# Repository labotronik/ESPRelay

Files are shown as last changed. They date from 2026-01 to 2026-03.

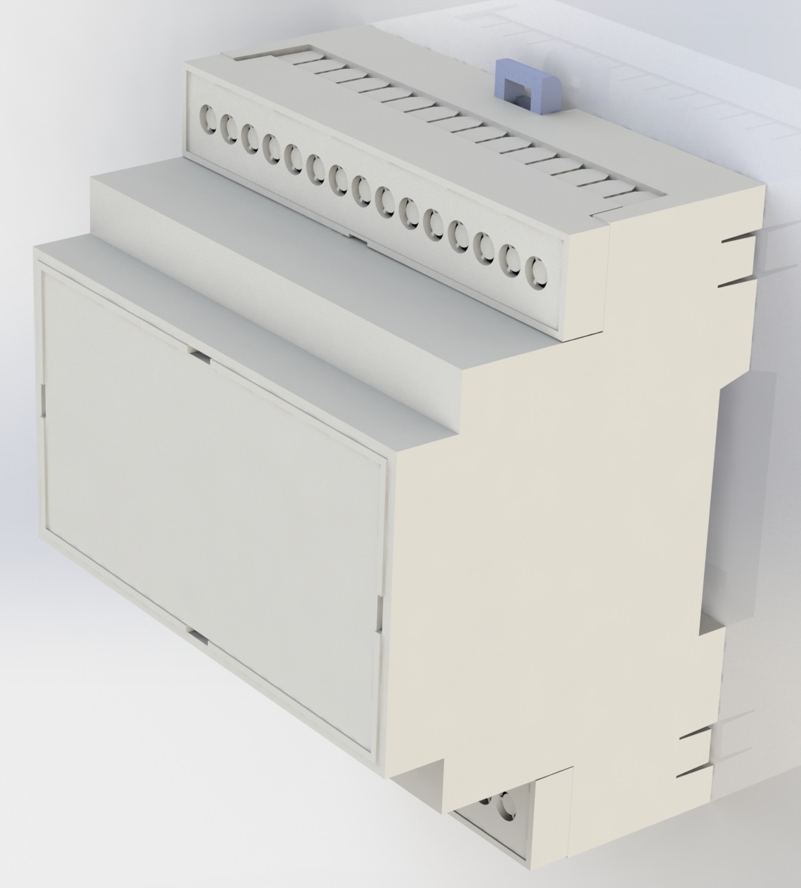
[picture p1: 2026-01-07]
kicad/enclosure/d5mg-1.snapshot.3/D5MG-FRONT.JPG

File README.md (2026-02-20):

# ESPRelay4

Documentation rapide d'utilisation de la carte relais (Ethernet, MQTT, Wi-Fi AP fallback, BLE) d'après le firmware actuel.

## 1) Démarrage et accès

- Le serveur HTTP écoute sur le port `80`.
- La page web principale est servie sur `/`.
- Réseau Ethernet W5500 actif au boot.

Configuration réseau par défaut (si aucun fichier de config):
- IP: `192.168.1.50`
- GW: `192.168.1.1`
- Mask: `255.255.255.0`
- DNS: `192.168.1.1`

## 2) API HTTP disponible

Endpoints principaux:
- `GET /api/state` -> état courant (inputs, relays, overrides, modules, réseau, volets, etc.)
- `GET /api/rules` -> règles simples + volets
- `GET /api/net` -> config réseau
- `GET /api/wifi` -> config/status Wi-Fi AP
- `GET /api/mqtt` -> config/status MQTT (transport actif, état GSM)
- `GET /api/backup` -> backup global
- `PUT /api/rules` -> applique des règles
- `PUT /api/net` -> applique réseau
- `PUT /api/wifi` -> active/désactive AP Wi-Fi
- `PUT /api/mqtt` -> applique config MQTT
- `POST /api/override` -> force un relais (`AUTO|FORCE_ON|FORCE_OFF`)
- `POST /api/shutter` -> commande volet (`UP|DOWN|STOP|AUTO`)
- `POST /api/ota` -> OTA firmware binaire
- `POST /api/otafs` -> OTA LittleFS binaire

Authentification:
- Défaut: `admin / admin`
- API de changement: `PUT /api/auth`

## 3) Utilisation MQTT (Ethernet + fallback GSM)

### 3.1 Principe de transport

Le firmware peut utiliser:
- broker local (Ethernet)
- broker GSM (A7670 + 1NCE)

Comportement actuel recommandé:
- tentative sur broker local d'abord
- si échec local, fallback sur broker GSM public (`gsm_mqtt_host`)

### 3.2 Paramètres MQTT (via `PUT /api/mqtt`)

Champs utiles:
- `enabled`: `1` pour activer MQTT
- `transport`: `ethernet`, `auto` ou `gsm`
- `host`, `port`, `user`, `pass`: broker principal (local)
- `gsm_mqtt_host`, `gsm_mqtt_port`, `gsm_mqtt_user`, `gsm_mqtt_pass`: broker GSM
- `client_id`: identifiant MQTT
- `base`: base topic (ex: `esprelay4`)
- `retain`: `1` recommandé pour récupérer un état immédiatement après subscribe
- `apn`, `gsm_user`, `gsm_pass`: paramètres data opérateur GSM

Exemple minimal:
```json
{
  "enabled": 1,
  "transport": "ethernet",
  "host": "192.168.1.43",
  "port": 1883,
  "gsm_mqtt_host": "82.64.24.196",
  "gsm_mqtt_port": 1883,
  "client_id": "ESPRelay4",
  "base": "esprelay4",
  "retain": 1,
  "apn": "iot.1nce.net",
  "gsm_user": "",
  "gsm_pass": ""
}
```

### 3.3 Commandes MQTT relais

Base topic par défaut: `esprelay4`

Relais 1:
- commande: `esprelay4/relay/1/set`
- payload: `ON`, `OFF`, `AUTO`, `TOGGLE`
- état: `esprelay4/relay/1/state`

Exemples:
```bash
mosquitto_sub -h 82.64.24.196 -p 1883 -t esprelay4/relay/1/state -v
mosquitto_pub -h 82.64.24.196 -p 1883 -t esprelay4/relay/1/set -m ON
```

Important:
- Si un relais est réservé à un volet, les overrides directs sont refusés/ignorés.
- `set ON/OFF` force le relais (override) tant que `AUTO` n'est pas envoyé.

### 3.4 Keepalive MQTT

- Paramètre firmware: `MQTT_KEEPALIVE_SECONDS`
- Valeur actuelle: `1800` secondes (30 min)

### 3.5 Mode GSM économie data

Quand transport actif = GSM:
- publication limitée aux états de pilotage utiles
- pas de discovery Home Assistant en boucle
- pas de télémétrie non essentielle en continu

## 4) Wi-Fi (AP fallback)

Le Wi-Fi est utilisé ici en mode AP local de maintenance.

- AP SoftAP activable/désactivable via `/api/wifi` ou MQTT:
  - `esprelay4/wifi/ap/set` avec payload `ON` ou `OFF`
- SSID par défaut: basé sur l'identifiant de la carte (`ESPRelay4-XXXXXX`)
- Mot de passe par défaut: `esprelay4`
- Captive portal simplifié (redirections vers l'IP AP)

## 5) BLE

Le firmware expose l'état en BLE (NimBLE):
- Device name: similaire au SSID (`ESPRelay4-XXXXXX`)
- Service UUID dynamique basé sur MAC:
  - `6E400001-B5A3-F393-E0A9-XXXXXXXXXXXX`
- Characteristic notify/read:
  - `6E400003-B5A3-F393-E0A9-XXXXXXXXXXXX` (READ + NOTIFY)
- Characteristic read:
  - `6E400004-B5A3-F393-E0A9-XXXXXXXXXXXX` (READ)

Particularités flux notify:
- cadence ~1 Hz
- tramage: `0x1E 0x1E + payload JSON + 0x1F`
- chunk BLE max ~160 bytes

Activation BLE:
- via MQTT: `esprelay4/ble/set` avec `ON`/`OFF`
- via API config BLE (`/ble.json`)

## 6) Règles / Volets / Priorités

Ordre de priorité des sorties:
1. Règles simples
2. Logique volet (si relais réservés)
3. Override manuel (MQTT/API) sur relais non réservés
4. Sécurité finale interlock volet

Conséquence:
- un `relay/x/set ON` écrase la règle tant que `AUTO` n'est pas renvoyé
- sur relais réservé volet: override interdit

## 7) Factory reset

- Maintenir le bouton factory (`IO0`) pendant ~10 secondes au boot
- Supprime les fichiers config: `/net.json`, `/mqtt.json`, `/rules.json`, `/auth.json`, `/wifi.json`, `/ble.json`
- Redémarrage automatique

## 8) Estimation conso data GSM

Hypothèses:
- Forfait: 500 Mo sur 10 ans
- Conso idle estimée: 10 Ko/jour
- 1 activation relais + lecture d'état MQTT: ~0,3 Ko

Seuil moyen:
- 500 Mo / 10 ans ~= 140 Ko/jour
- Après idle (10 Ko/jour), il reste ~130 Ko/jour pour les actions

Cas d'usage pouvant vider 500 Mo:
- ~430 activations/jour avec lecture d'état, sur la durée
- ou moins si réseau instable (reconnexions MQTT fréquentes)
- OTA via GSM: plusieurs Mo ponctuels

Exemple à risque:
- ~150 activations/jour + ~10 à 15 reconnexions MQTT/jour sur la durée

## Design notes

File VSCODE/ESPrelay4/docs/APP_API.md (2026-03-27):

# Documentation — ESPRelay4

## Vue d’ensemble
ESPRelay4 est un firmware ESP32‑S3 qui pilote des modules PCA9538 (I2C) et expose :
- une interface Web (LittleFS) ;
- une API HTTP JSON ;
- MQTT (avec auto‑découverte Home Assistant).

Fonctions principales :
- Entrées digitales (E*) via PCA9538 ;
- Relais (R*) via PCA9538 ;
- Règles logiques (FOLLOW/AND/OR/XOR/TOGGLE/PULSE) ;
- Volets (jusqu’à 2, 2 relais chacun, interlock + dead‑time) ;
- Réseau (DHCP ou statique) ;
- MQTT configurable ;
- Backup/restore complet ;
- Capteurs température DS18B20 (1‑Wire) et DHT22.

---

## Matériel & bus
### I2C / PCA9538
- PCA9538 adressés à partir de `0x70`.
- Scan automatique `0x70..0x73` (max 4 modules).
- Chaque module = 4 sorties + 4 entrées :
  - IO0..IO3 = relais (R)
  - IO4..IO7 = entrées (E)

### 1‑Wire / DS18B20
- Broche configurable : `PIN_ONEWIRE` (IO1 par défaut).

### DHT22
- Broche configurable : `PIN_DHT` (IO2 par défaut).

---

## Numérotation E/R
Les entrées et relais sont **globaux** :
- Module 1 : E1..E4, R1..R4
- Module 2 : E5..E8, R5..R8
- Module 3 : E9..E12, R9..R12
- Module 4 : E13..E16, R13..R16

L’UI propose une vue par module, mais les règles utilisent l’index global.

---

## Règles (rules.json)
Structure (résumé) :
```json
{
  "version": 2,
  "relays": [
    {
      "expr": { "op": "FOLLOW", "in": 1 },
      "invert": false,
      "onDelay": 0,
      "offDelay": 0,
      "pulseMs": 200
    }
  ],
  "shutters": []
}
```
### Opérateurs
- `FOLLOW` : suit une entrée
- `AND`, `OR`, `XOR` : logique multi‑entrées
- `TOGGLE_RISE` : bascule sur front montant
- `PULSE_RISE` : pulse sur front montant

### Volets (shutters[])
Jusqu’à 2 volets :
```json
{
  "name": "Volet 1",
  "up_in": 1,
  "down_in": 2,
  "up_relay": 1,
  "down_relay": 2,
  "mode": "hold",
  "priority": "stop",
  "deadtime_ms": 400,
  "max_run_ms": 25000
}
```
Contraintes :
- `up_relay` ≠ `down_relay`
- Les deux volets ne doivent pas partager de relais

---

## API HTTP
### GET /
Servir la page Web depuis LittleFS.

### GET /api/state
État global (entrées, relais, overrides, volets, capteurs, réseau).
```json
{
  "inputs": [0,1,...],
  "relays": [0,1,...],
  "override": [-1,0,1,...],
  "reserved": [0,1,...],
  "eth": { "link": 1, "ip": "192.168.1.50" },
  "shutter": { "enabled": 1, "name": "Volet 1", "up_relay": 1, "down_relay": 2, "move": "up", "cooldown_ms": 0 },
  "shutters": [
    { "enabled": 1, "name": "Volet 1", "up_relay": 1, "down_relay": 2, "move": "up", "cooldown_ms": 0 },
    { "enabled": 0 }
  ],
  "temps": [
    { "addr": "28FF...", "c": 21.45 },
    { "addr": "DHT22", "c": 22.10, "h": 48.2 }
  ],
  "modules": 2,
  "relays_per": 4,
  "inputs_per": 4,
  "total_relays": 8,
  "total_inputs": 8,
  "uptime_ms": 12345678
}
```

### GET /api/rules
Retourne le JSON complet des règles (relays + shutters).

### PUT /api/rules
Remplace toutes les règles.
- Validation taille `relays` = `total_relays`.
- Validation volets + conflits de relais.

### POST /api/override
```json
{ "relay": 1, "mode": "AUTO|FORCE_ON|FORCE_OFF" }
```
Refus si relais réservé par volet.

### POST /api/shutter
```json
{ "id": 1, "cmd": "UP|DOWN|STOP|AUTO" }
```
`id` ∈ {1,2}

### GET /api/net
Config réseau (inclut MAC Ethernet).

### PUT /api/net
```json
{
  "mode": "dhcp|static",
  "ip": "192.168.1.50",
  "gw": "192.168.1.1",
  "sn": "255.255.255.0",
  "dns": "192.168.1.1"
}
```

### GET /api/mqtt
Config MQTT (inclut état connecté).

### PUT /api/mqtt
```json
{
  "enabled": 1,
  "transport": "ethernet|gsm|auto",
  "host": "192.168.1.43",
  "port": 1883,
  "user": "",
  "pass": "",
  "client_id": "ESPRelay4",
  "base": "esprelay4",
  "discovery_prefix": "homeassistant",
  "retain": 1,
  "apn": "iot.1nce.net",
  "gsm_user": "",
  "gsm_pass": ""
}
```

Règle transport:
- `gsm` : active uniquement le client MQTT GSM.
- `ethernet` : active uniquement le client MQTT Ethernet.
- `auto` : active le client MQTT Ethernet, et active aussi le client MQTT GSM si `gsm_mqtt_host` est configuré.

### GET /api/backup
Retourne un backup complet :
```json
{ "rules": { ... }, "net": { ... }, "mqtt": { ... } }
```

### PUT /api/backup
Applique et redémarre la carte.

---

## MQTT (Home Assistant)
### Disponibilité
`<base>/status` = `online|offline`

### Relais
- `base/relay/<n>/set` (ON/OFF/AUTO)
- `base/relay/<n>/state`

### Entrées
- `base/input/<n>/state`

### Volets
2 covers :
- `base/shutter/1/set` / `base/shutter/1/state`
- `base/shutter/2/set` / `base/shutter/2/state`
Payloads : OPEN / CLOSE / STOP

### Températures
DS18B20 :
- `base/temp/<n>/state`

DHT22 :
- Température : `base/temp/dht/state`
- Humidité : `base/hum/dht/state`

---

## UI Web
Onglets :
- Dashboard : état entrées/relais/volets + capteurs si détectés
- Programmation : règles + volets 1/2
- JSON : vue JSON complet
- Réseau : IP + MQTT
- Backup : export / import

---

## Notes
- `millis()` overflow ~49,7 jours → uptime repart à 0.
- Les relais réservés par volet ignorent overrides et règles simples.

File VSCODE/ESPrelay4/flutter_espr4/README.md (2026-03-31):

# flutter_espr4

A new Flutter project.

## Getting Started

This project is a starting point for a Flutter application.

A few resources to get you started if this is your first Flutter project:

- [Learn Flutter](https://docs.flutter.dev/get-started/learn-flutter)
- [Write your first Flutter app](https://docs.flutter.dev/get-started/codelab)
- [Flutter learning resources](https://docs.flutter.dev/reference/learning-resources)

For help getting started with Flutter development, view the
[online documentation](https://docs.flutter.dev/), which offers tutorials,
samples, guidance on mobile development, and a full API reference.

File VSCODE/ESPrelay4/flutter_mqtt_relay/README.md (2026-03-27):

# flutter_mqtt_relay

Application Flutter MQTT pour piloter la carte ESPRelay4.

## Lancement

```bash
cd flutter_mqtt_relay
flutter pub get
flutter run
```

## Configuration MQTT

Dans l'onglet `MQTT`:

- `Broker host`: IP ou DNS du broker.
- `Broker port`: port MQTT (1883 par defaut).
- `Username` / `Password`: optionnel.
- `Base topic`: ex. `esprelay4`.
- `Client ID`: identifiant MQTT du client Flutter.

Puis cliquer `Save + Connect`.

## Setup relais

Dans l'onglet `Setup`, vous pouvez renommer les relais `R1..R4`.
Les noms sont sauvegardes localement dans l'application.

## Topics utilises

Commandes relais:

- `<base>/relay/1/set` payload `ON|OFF|AUTO`

Etats ecoutes:

- `<base>/status` (`online/offline`)
- `<base>/net/ip`
- `<base>/relay/<n>/state`
- `<base>/input/<n>/state`
- `<base>/vin/<n>/state`

L'interface reprend la presentation de la page Ethernet:

- bandeau de statuts (pills),
- onglet `Input` dedie aux etats des entrees `E1..E4` et `VIN`,
- cartes modules (dashboard),
- lignes relais avec etat/entree et actions `ON/OFF/AUTO`.

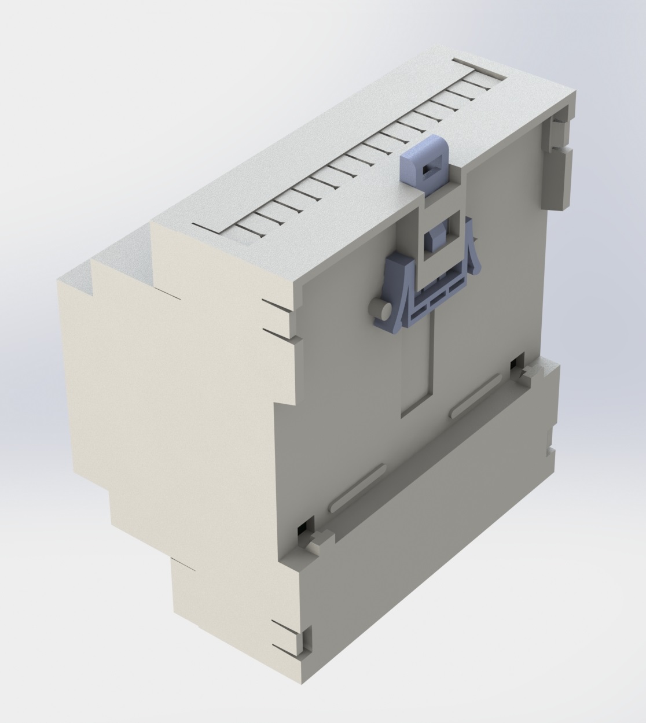
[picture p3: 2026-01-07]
kicad/enclosure/d5mg-1.snapshot.3/D5MG-REAR.JPG

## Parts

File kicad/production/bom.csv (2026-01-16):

Designator | Footprint | Quantity | Value | LCSC Part #
C1, C10, C11, C13, C2, C4, C5, C6, C8, C9 | 0402 | 10 | 100nF
C12 | 0805 | 1 | 10µF
C14 | 0402 | 1 | 22nF
C15, C17 | 0402 | 2 | 6.8nF
C16, C20, C7 | 0402 | 3 | 10nF
C18, C19 | 0402 | 2 | 12pF
C21 | 0402 | 1 | 4.7µF
C3 | CP_Elec_4x5.4 | 1 | 10µF
D1 | D_SMB | 1 | SMBJ12A
D2, D3, D4 | D_SMA | 3 | B230A-13-F
D5 | 0603 | 1 | LED LTST-C193TGKT-5A
F1 | 0154250DR littelfuse 10.62 3.81 | 1 | Fuse 3A
J1 | PhoenixContact_MCV_1,5_2-G-3.5_1x02_P3.50mm_Vertical | 1 | POWER_INPUT
J10, J7, J8, J9 | PhoenixContact_MCV_1,5_3-G-3.5_1x03_P3.50mm_Vertical | 4 | Screw_Terminal_01x03
J11 | PhoenixContact_MCV_1,5_6-G-3.5_1x06_P3.50mm_Vertical | 1 | Screw_Terminal_01x06
J2 | USB_C_Receptacle_G-Switch_GT-USB-7051x | 1 | GT-USB-7051A
J3 | Molex_54548-1071_1x10-1MP_P0.5mm_Horizontal | 1 | MOLEX 545480671
J4 | RJ12_Amphenol_54601-x06_Horizontal | 1 | RJ12
J5 | a7670c module | 1 | A7670C MODULE
J6 | RJ45_Hanrun_HR911105A_Horizontal | 1 | HR911105A
JP1 | PinHeader_1x02_P2.54mm_Vertical | 1 | Jumper_2_Bridged
K1, K2, K3, K4 | Relay_SPDT_Schrack-RT1-16A-FormC_RM5mm | 4 | RZ03-1C4-D012
Q1 | SOIC127P1030X245-18N | 1 | TBD62083AFG_EL
R1, R2, R6 | 0402 | 3 | 10k
R10, R11, R13, R9 | 0402 | 4 | 49.9
R12 | 0402 | 1 | 10
R14, R7, R8 | 0402 | 3 | 1k
R15 | 0402 | 1 | 1M
R16 | 0402 | 1 | 12.4k 1%
R17, R18, R19, R20 | 0805 | 4 | 2.2k
R21, R22, R23, R24, R3, R5 | 0402 | 6 | 4k7
R4 | 0402 | 1 | 680
SW1 | SW_Tactile_SPST_NO_Straight_CK_PTS636Sx25SMTRLFS | 1 | SW_Push
U1 | TO-263-3_TabPin2 | 1 | MC7805BD2TR4G
U2 | ESP32-S3-WROOM-1 | 1 | ESP32-S3-WROOM-1-N4
U3 | TO-252-2 | 1 | LF33CDT-TR
U4 | NXP_VQFN-16-1EP_4x4mm_P0.65mm_EP2.1x2.1mm | 1 | PCA9538BS
U5 | LQFP-48_7x7mm_P0.5mm | 1 | W5500
U6 | SOP-16_4.4x10.4mm_P1.27mm | 1 | TCMT4100
Y1 | Crystal_SMD_2016-4Pin_2.0x1.6mm | 1 | X201625MOB4SI - 25Mhz

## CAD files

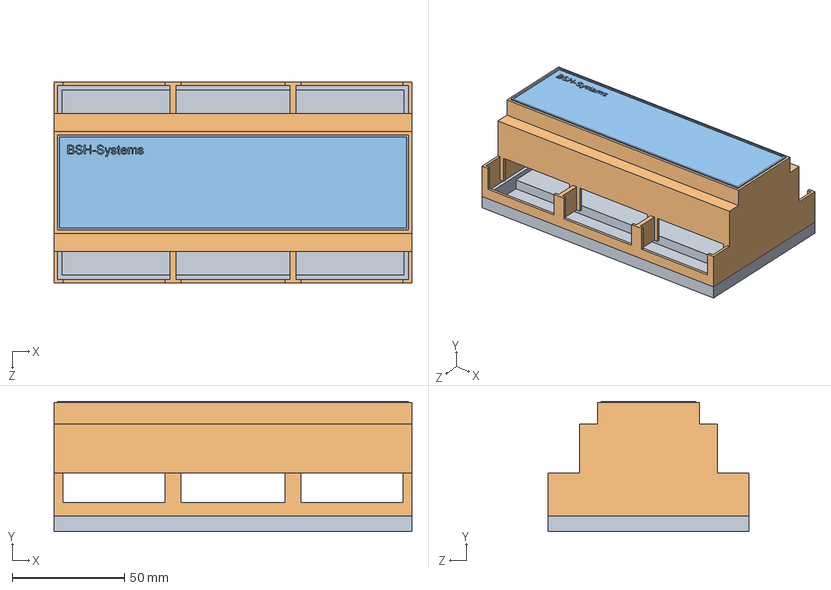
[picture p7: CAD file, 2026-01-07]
kicad/step files/User Library-D9MG_Asm.STEP
159.5 x 58.0 x 89.5 mm
D9MG_Bottom_Å« π¼«½τá¡¿ε
D9MG_Top_Å« π¼«½τá¡¿ε
D9MG_Closer_BSH_Å« π¼«½τá¡¿ε

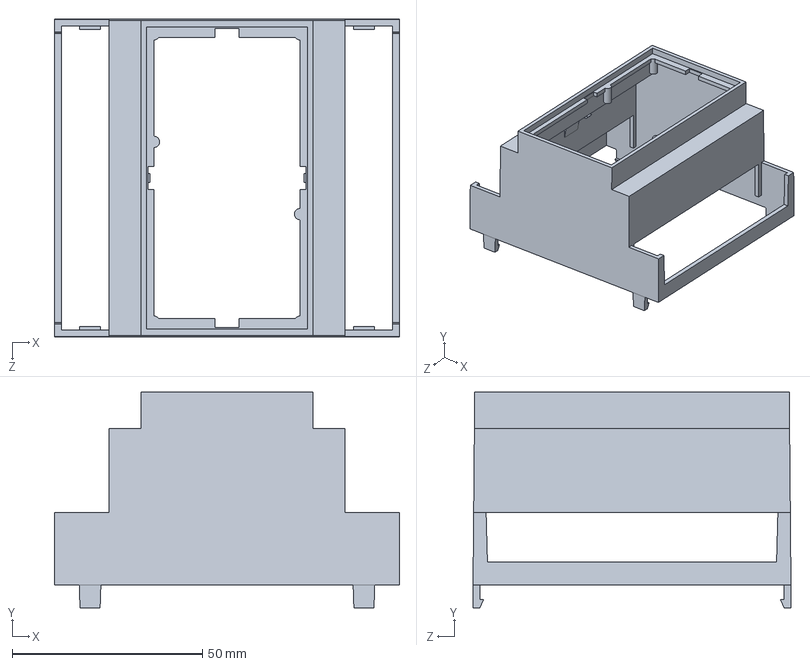
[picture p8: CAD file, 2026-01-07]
kicad/enclosure/d5mg-1.snapshot.3/D5MG-BODY.SLDPRT
90.7 x 56.7 x 83.6 mm

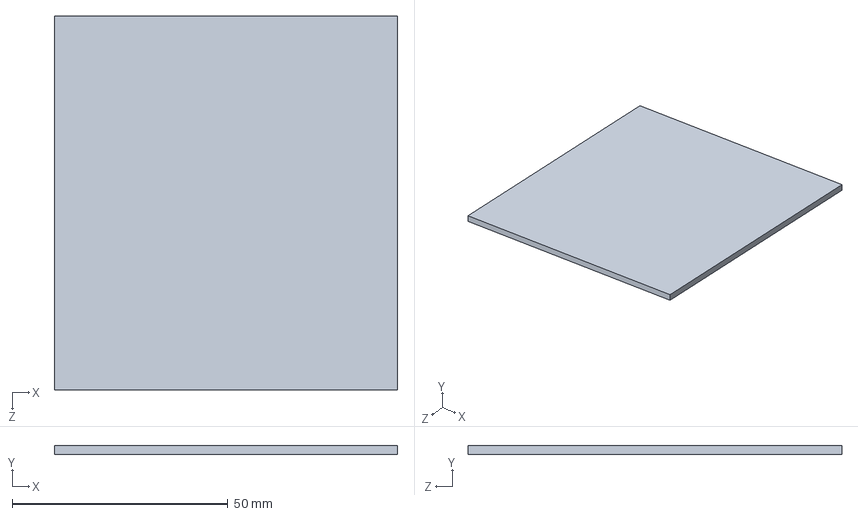
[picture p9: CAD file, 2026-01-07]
kicad/enclosure/d5mg-1.snapshot.3/PCB-BOT.SLDPRT
79.5 x 2.00 x 86.6 mm

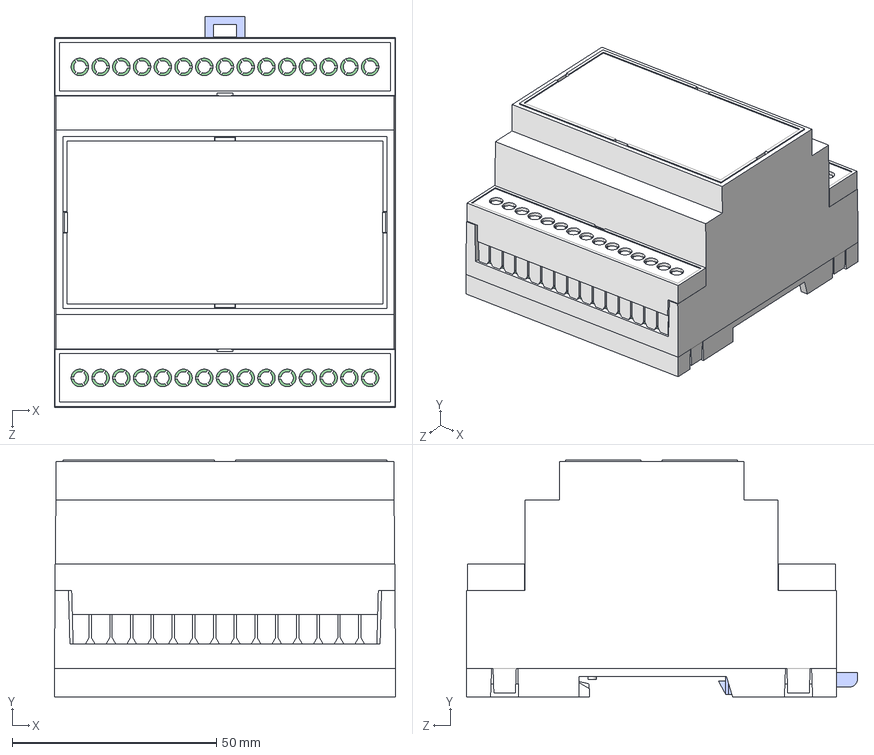
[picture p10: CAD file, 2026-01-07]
kicad/enclosure/d5mg-1.snapshot.3/D5MG.STEP
83.6 x 58.0 x 95.8 mm
D5MG-BODY
PCB-TOP
PCB-MID
PCB-BOT
D5MG-BASE
D5MG-COVER
D5MG-GUARD x 2
D5MG-WALL CLIP

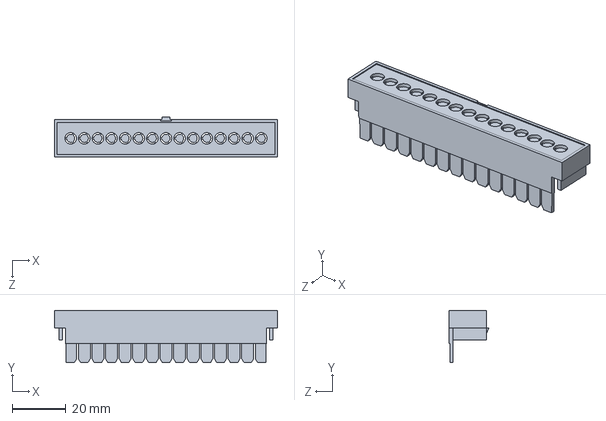
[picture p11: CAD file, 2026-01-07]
kicad/enclosure/d5mg-1.snapshot.3/D5MG-GUARD.SLDPRT
83.2 x 19.5 x 14.9 mm

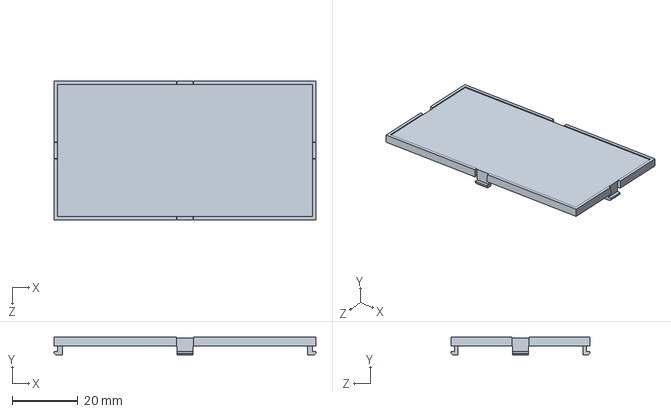
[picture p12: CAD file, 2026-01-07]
kicad/enclosure/d5mg-1.snapshot.3/D5MG-COVER.SLDPRT
79.5 x 5.40 x 42.2 mm

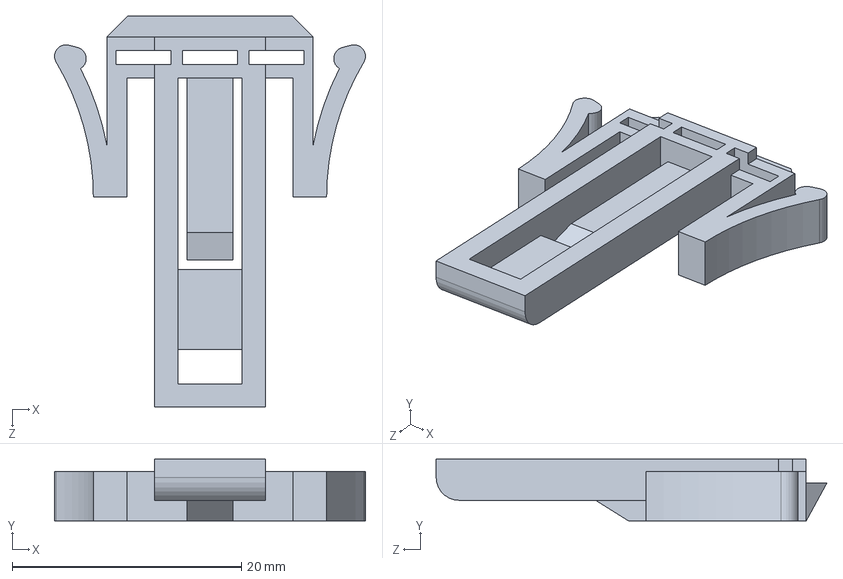
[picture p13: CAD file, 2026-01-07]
kicad/enclosure/d5mg-1.snapshot.3/D5MG-WALL CLIP.SLDPRT
27.1 x 5.40 x 34.1 mm

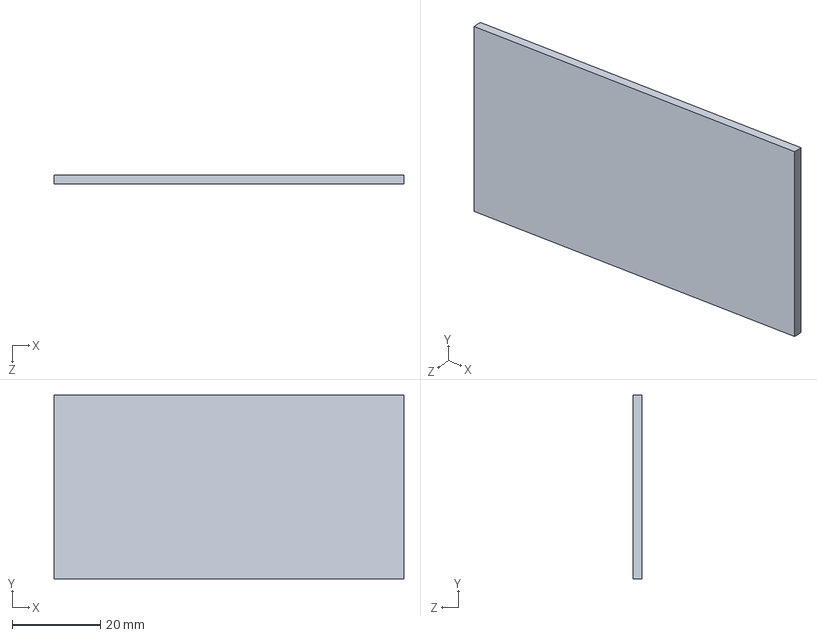
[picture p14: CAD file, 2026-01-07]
kicad/enclosure/d5mg-1.snapshot.3/PCB-TOP.SLDPRT
79.5 x 41.7 x 2.00 mm

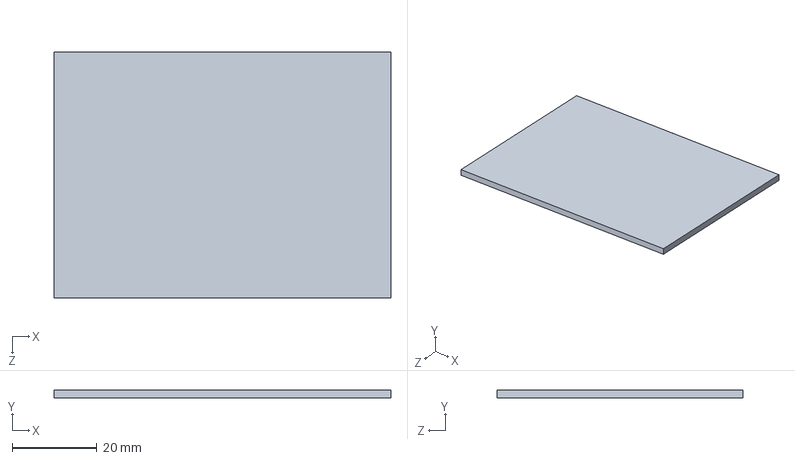
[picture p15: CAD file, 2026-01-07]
kicad/enclosure/d5mg-1.snapshot.3/PCB-MID.SLDPRT
79.5 x 2.00 x 58.1 mm

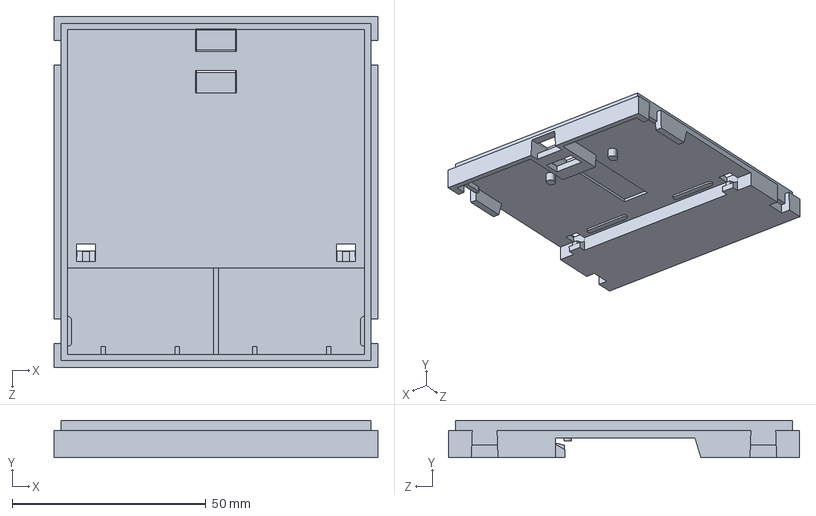
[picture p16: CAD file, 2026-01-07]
kicad/enclosure/d5mg-1.snapshot.3/D5MG-BASE.SLDPRT
83.6 x 9.60 x 90.7 mm

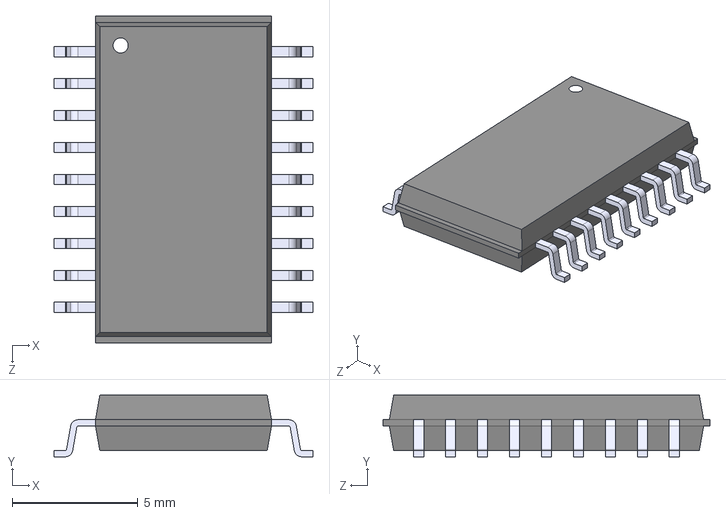
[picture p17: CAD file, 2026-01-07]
kicad/TBD62083AFG_EL/TBD62083AFG_EL.step
10.3 x 2.45 x 13.0 mm

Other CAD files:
kicad/enclosure/d5mg-1.snapshot.3/D5MG.SLDASM

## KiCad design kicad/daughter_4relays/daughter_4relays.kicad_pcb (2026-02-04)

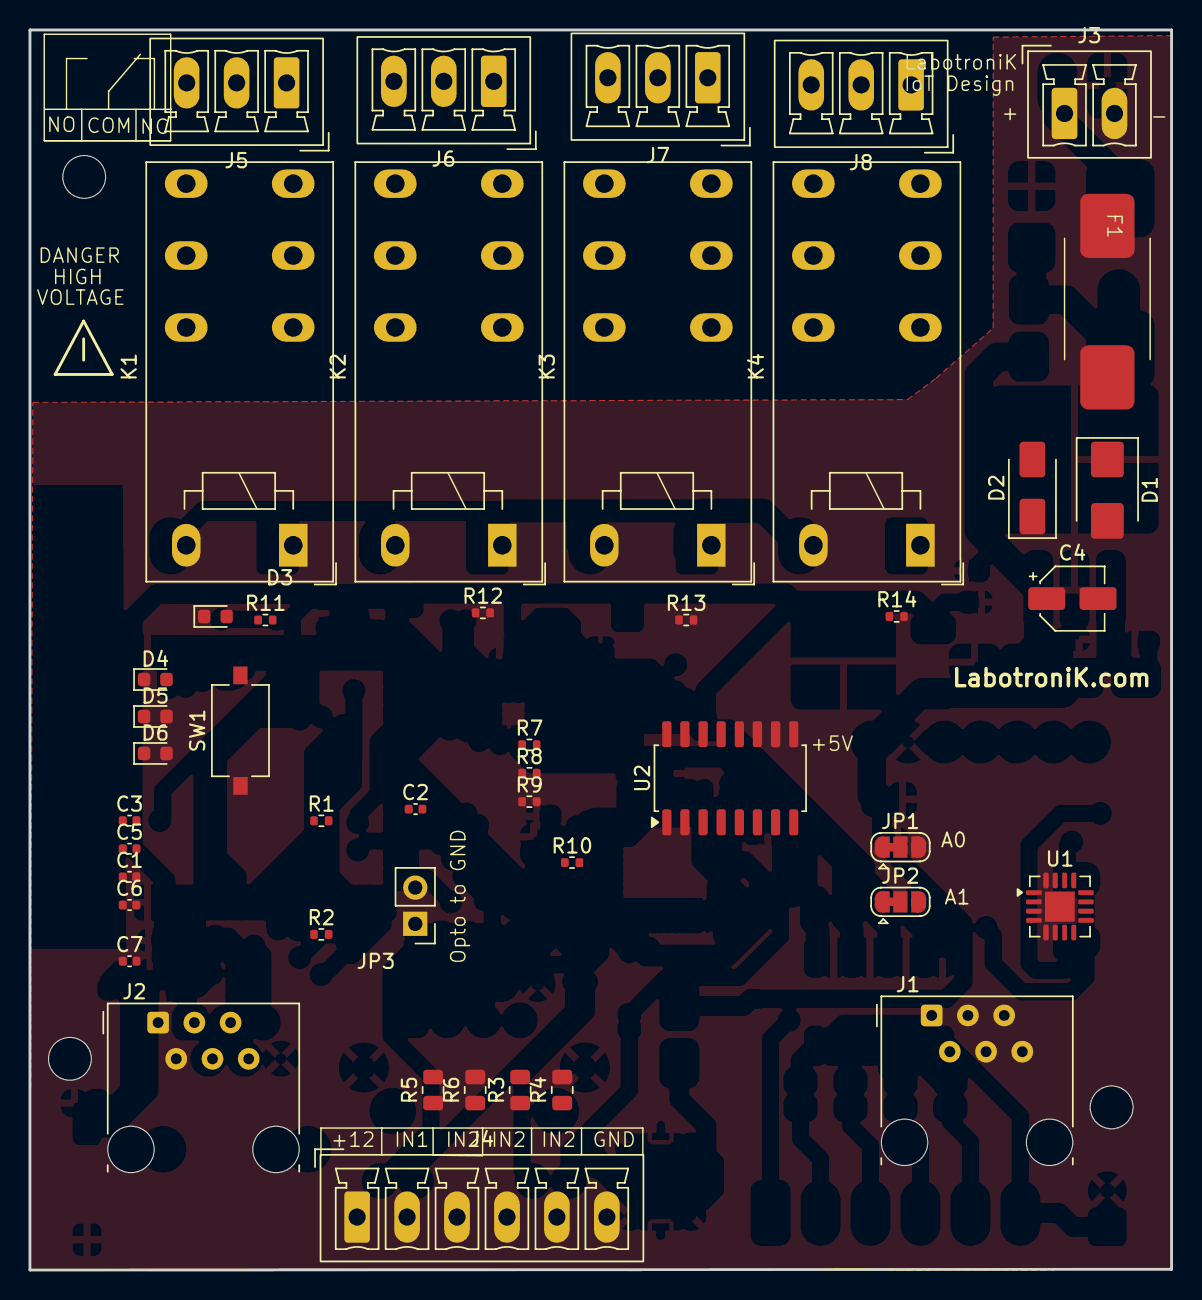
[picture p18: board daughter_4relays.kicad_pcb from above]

Board: 2 copper layers, 80.0 x 86.9 mm, 46 parts (0 on the bottom side), 47 nets, no tracks yet.

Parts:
C1, C2, C3, C5, C6, C7: 100nF; C_0402_1005Metric
C4: 10µF; CP_Elec_4x5.4
D1: SMBJ12A; D_SMB
D2: B230A-13-F; D_SMA
D3, D4, D5, D6: LED LTST-C193TGKT-5A; LED_0603_1608Metric
F1: Fuse 3A; 0154250DR littelfuse 10.62 3.81
J1, J2: RJ12; RJ12_Amphenol_54601-x06_Horizontal
J3: POWER_INPUT; PhoenixContact_MCV_1,5_2-G-3.5_1x02_P3.50mm_Vertical
J4: Screw_Terminal_01x06; PhoenixContact_MCV_1,5_6-G-3.5_1x06_P3.50mm_Vertical
J5, J6, J7, J8: Screw_Terminal_01x03; PhoenixContact_MCV_1,5_3-G-3.5_1x03_P3.50mm_Vertical
JP1, JP2: SolderJumper_3_Bridged12; SolderJumper-3_P1.3mm_Bridged12_RoundedPad1.0x1.5mm
JP3: Jumper_2_Bridged; PinHeader_1x02_P2.54mm_Vertical
K1, K2, K3, K4: RZ03-1C4-D012; Relay_SPDT_Schrack-RT1-16A-FormC_RM5mm
R1, R2: 10k; R_0402_1005Metric
R3, R4, R5, R6: 2.2k; R_0805_2012Metric
R7, R8, R9, R10: 4k7; R_0402_1005Metric
R11, R12, R13, R14: 680; R_0402_1005Metric
SW1: SW_Push; SW_Tactile_SPST_NO_Straight_CK_PTS636Sx25SMTRLFS
U1: PCA9538BS; NXP_VQFN-16-1EP_4x4mm_P0.65mm_EP2.1x2.1mm
U2: TCMT4100; SOP-16_4.4x10.4mm_P1.27mm

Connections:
+3.3V: C1.1, C2.1, C6.1, J1.1, J2.1, JP1.3 (B), JP2.3 (B), R1.1, R2.2, R7.1, R8.1, R9.1, R10.1, U1.14 (V_{DD})
+12V: C4.1, C5.1, C7.1, D2.1 (K), J4.1
/IO1: J1.4, J2.4
/IO2: J1.5, J2.5
/SCL: J1.3, J2.3, U1.12 (SCL)
/SDA: J1.2, J2.2, U1.13 (SDA)
/input/IN1: J4.2, R5.1
/input/IN2: J4.3, R6.1
/input/IN3: J4.4, R3.1
/input/IN4: J4.5, R4.1
/input/OPTO_GND: J4.6, JP3.1 (A), U2.2, U2.4, U2.6, U2.8
/input/input1: R8.2, U1.7 (IO4), U2.16
/input/input2: R9.2, U1.8 (IO5), U2.14
/input/input3: R7.2, U1.9 (IO6), U2.12
/input/input4: R10.2, U1.10 (IO7), U2.10
/relais/PWR_KM1: K1.A1, R11.1
/relais/PWR_KM2: K2.A1, R12.1
/relais/PWR_KM3: K3.A1, R13.1
/relais/PWR_KM4: K4.A1, R14.1
GND: C1.2, C2.2, C3.2, C6.2, C7.2, D3.1 (K), D4.1 (K), D5.1 (K), D6.1 (K), J1.6, J2.6, JP1.1 (A), JP2.1 (A), JP3.2 (B), K1.A2, K2.A2, K3.A2, K4.A2, SW1.1, U1.6 (V_{SS}), U1.17 (V_{SS}), U2.9, U2.11, U2.13, U2.15
unnamed: C3.1, R1.2, SW1.2
unnamed: D1.1 (A1), D2.2 (A), F1.2
unnamed: C4.2, C5.2, D1.2 (A2), J3.1
unnamed: D3.2 (A), R11.2
unnamed: D4.2 (A), R12.2
unnamed: D5.2 (A), R13.2
unnamed: D6.2 (A), R14.2
unnamed: F1.1, J3.2
unnamed: J5.1, K1.12
unnamed: J5.2, K1.11
unnamed: J5.3, K1.14
unnamed: J6.1, K2.12
unnamed: J6.2, K2.11
unnamed: J6.3, K2.14
unnamed: J7.1, K3.12
unnamed: J7.2, K3.11
unnamed: J7.3, K3.14
unnamed: J8.1, K4.12
unnamed: J8.2, K4.11
unnamed: J8.3, K4.14
unnamed: JP1.2 (C), U1.15 (A0)
unnamed: JP2.2 (C), U1.16 (A1)
unnamed: R3.2, U2.5
unnamed: R4.2, U2.7
unnamed: R5.2, U2.1
unnamed: R6.2, U2.3
unnamed: R2.1, U1.1 (~RESET)

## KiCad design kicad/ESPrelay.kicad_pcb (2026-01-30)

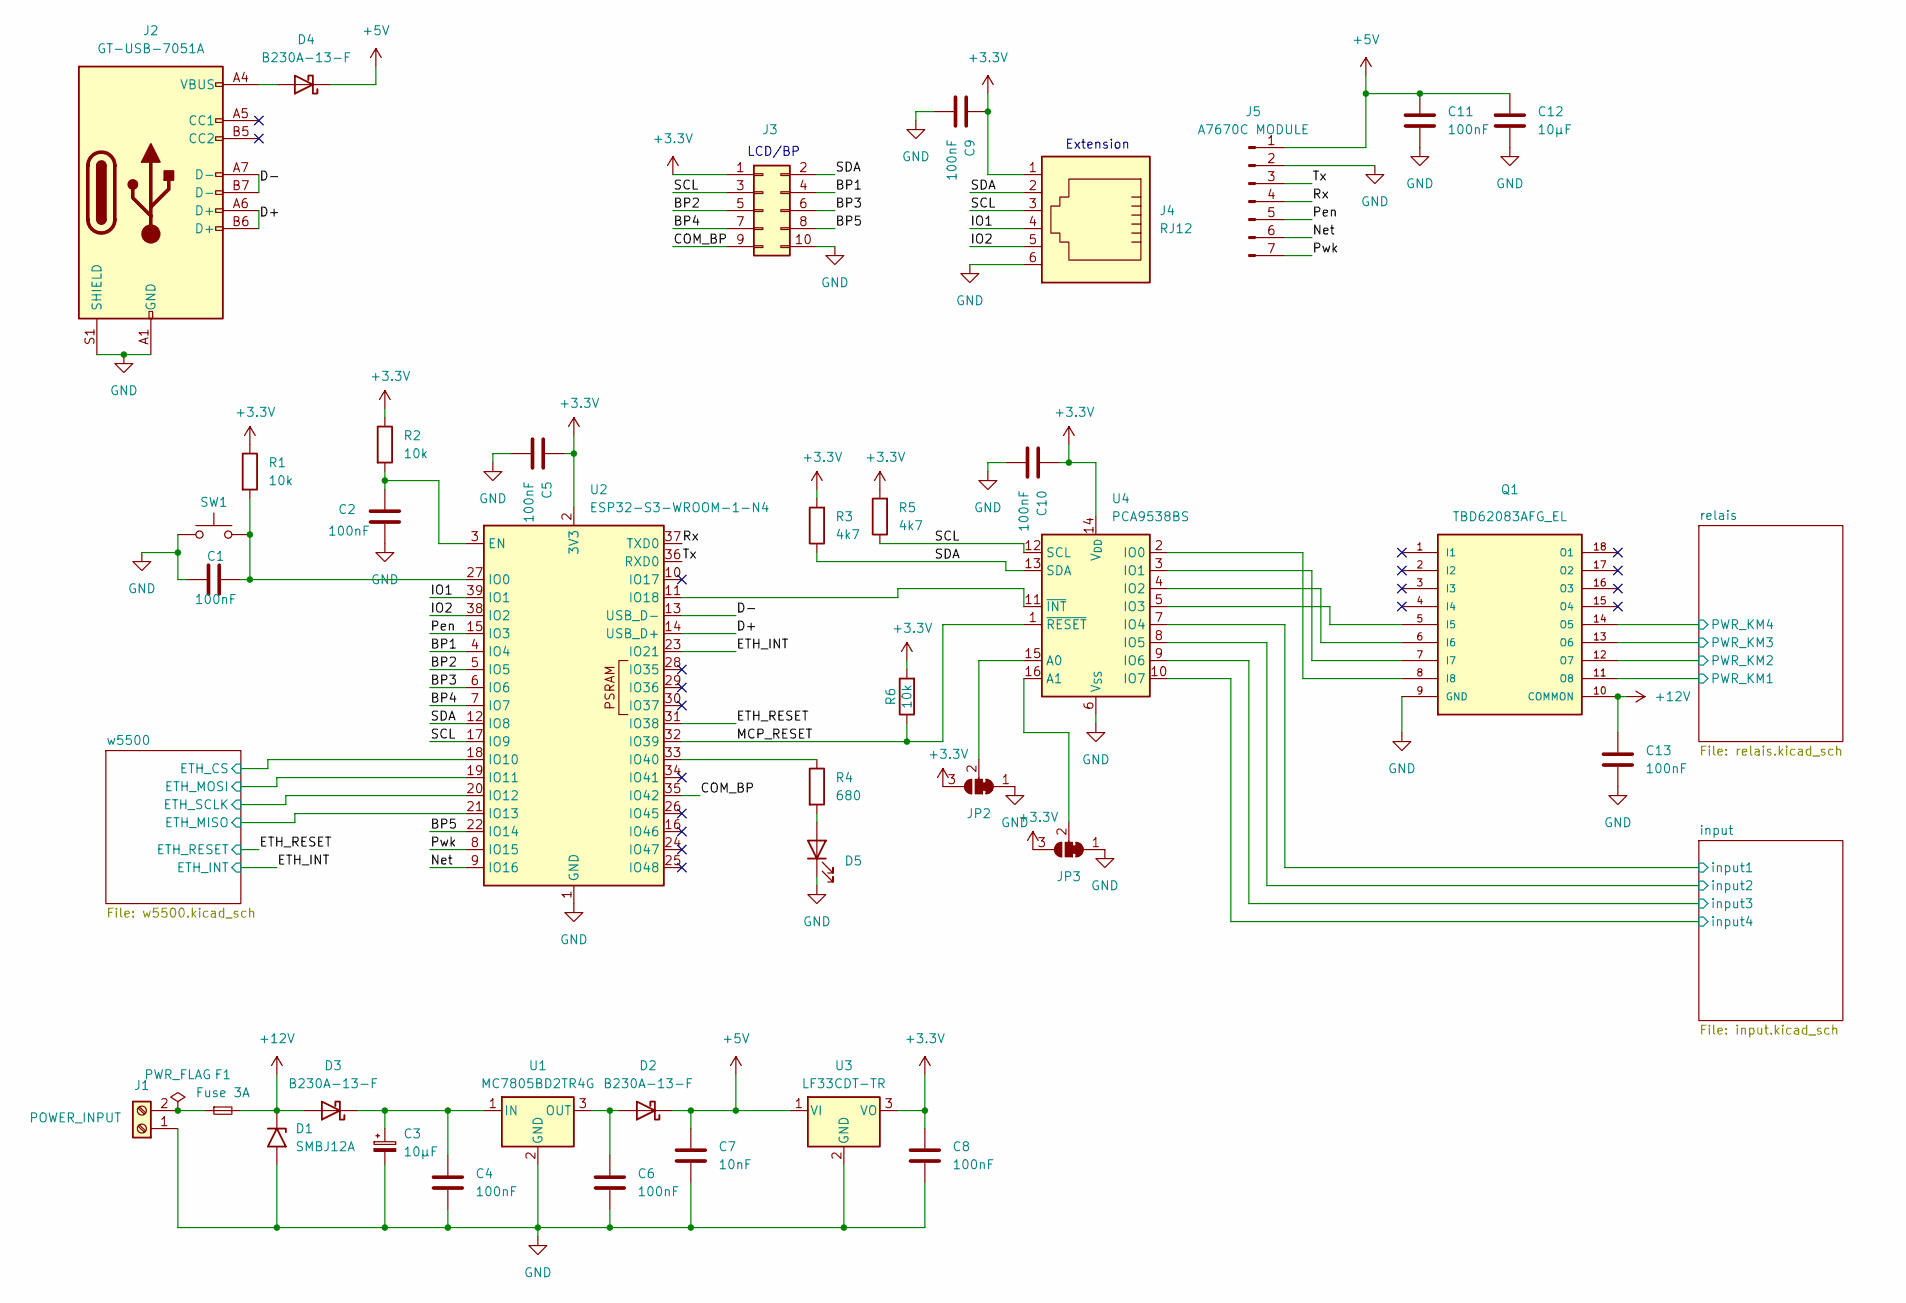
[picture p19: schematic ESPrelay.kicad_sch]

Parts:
C1, C2, C4, C5, C6, C8, C9, C10, C11, C13: 100nF; C_0402_1005Metric
C3: 10µF; CP_Elec_4x5.4
C7: 10nF; R_0402_1005Metric
C12: 10µF; C_0805_2012Metric
D1: SMBJ12A; D_SMB
D2, D3, D4: B230A-13-F; D_SMA
D5: LED LTST-C193TGKT-5A; LED_0603_1608Metric
F1: Fuse 3A; 0154250DR littelfuse 10.62 3.81
J1: POWER_INPUT; PhoenixContact_MCV_1,5_2-G-3.5_1x02_P3.50mm_Vertical
J2: GT-USB-7051A; USB_C_Receptacle_G-Switch_GT-USB-7051x
J3: MOLEX 545480671; Molex_54548-1071_1x10-1MP_P0.5mm_Horizontal
J4: RJ12; RJ12_Amphenol_54601-x06_Horizontal
J5: A7670C MODULE; a7670c module
JP2, JP3: SolderJumper_3_Bridged12; SolderJumper-3_P1.3mm_Bridged12_RoundedPad1.0x1.5mm
Q1: TBD62083AFG_EL; SOIC127P1030X245-18N; MOUSER_PART_NUMBER 757-TBD62083AFGEL
R1, R2, R6: 10k; R_0402_1005Metric
R3, R5: 4k7; R_0402_1005Metric
R4: 680; R_0402_1005Metric
SW1: SW_Push; SW_Tactile_SPST_NO_Straight_CK_PTS636Sx25SMTRLFS
U1: MC7805BD2TR4G; TO-263-3_TabPin2
U2: ESP32-S3-WROOM-1-N4; ESP32-S3-WROOM-1
U3: LF33CDT-TR; TO-252-2
U4: PCA9538BS; NXP_VQFN-16-1EP_4x4mm_P0.65mm_EP2.1x2.1mm

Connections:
+3.3V: C5.1, C8.1, C9.1, C10.1, J3.1, J4.1, JP2.3 (B), JP3.3 (B), R1.1, R2.1, R3.2, R5.2, R6.2, U2.2 (3V3), U3.3 (VO), U4.14 (V_{DD}); also elsewhere on the board
+5V: C7.1, C11.1, C12.1, D2.1 (K), D4.1 (K), J5.1, U3.1 (VI)
+12V: C13.1, D1.1 (A1), D3.2 (A), F1.2, Q1.10 (COMMON); also elsewhere on the board
/BP1: J3.4, U2.4 (IO4)
/BP2: J3.5, U2.5 (IO5)
/BP3: J3.6, U2.6 (IO6)
/BP4: J3.7, U2.7 (IO7)
/BP5: J3.8, U2.22 (IO14)
/COM_BP: J3.9, U2.35 (IO42)
/D+: J2.A6 (D+), J2.B6 (D+), U2.14 (USB_D+)
/D-: J2.A7 (D-), J2.B7 (D-), U2.13 (USB_D-)
/ETH_INT: U2.23 (IO21); also elsewhere on the board
/ETH_RESET: U2.31 (IO38); also elsewhere on the board
/IO1: J4.4, U2.39 (IO1)
/IO2: J4.5, U2.38 (IO2)
/MCP_RESET: R6.1, U2.32 (IO39), U4.1 (~RESET)
/Net: J5.6, U2.9 (IO16)
/Pen: J5.5, U2.15 (IO3)
/Pwk: J5.7, U2.8 (IO15)
/Rx: J5.4, U2.37 (TXD0)
/SCL: J3.3, J4.3, R5.1, U2.17 (IO9), U4.12 (SCL)
/SDA: J3.2, J4.2, R3.1, U2.12 (IO8), U4.13 (SDA)
/Tx: J5.3, U2.36 (RXD0)
/input/input1: U4.7 (IO4); also elsewhere on the board
/input/input2: U4.8 (IO5); also elsewhere on the board
/input/input3: U4.9 (IO6); also elsewhere on the board
/input/input4: U4.10 (IO7); also elsewhere on the board
/relais/PWR_KM1: Q1.11 (O8); also elsewhere on the board
/relais/PWR_KM2: Q1.12 (O7); also elsewhere on the board
/relais/PWR_KM3: Q1.13 (O6); also elsewhere on the board
/relais/PWR_KM4: Q1.14 (O5); also elsewhere on the board
/w5500/ETH_CS: U2.18 (IO10); also elsewhere on the board
/w5500/ETH_MISO: U2.21 (IO13); also elsewhere on the board
/w5500/ETH_MOSI: U2.19 (IO11); also elsewhere on the board
/w5500/ETH_SCLK: U2.20 (IO12); also elsewhere on the board
GND: C1.2, C2.2, C3.2, C4.2, C5.2, C6.2, C7.2, C8.2, C9.2, C10.2, C11.2, C12.2, C13.2, D1.2 (A2), D5.1 (K), J1.1, J2.A1 (GND), J2.A12 (GND), J2.B1 (GND), J2.B12 (GND), J2.S1 (SHIELD), J3.10, J4.6, J5.2, JP2.1 (A), JP3.1 (A), Q1.9 (GND), SW1.1, U1.2 (GND), U2.1 (GND), U2.40 (GND), U2.41 (GND), U3.2 (GND), U4.6 (V_{SS}), U4.17 (V_{SS}); also elsewhere on the board
unnamed: C6.1, D2.2 (A), U1.3 (OUT)
unnamed: C3.1, C4.1, D3.1 (K), U1.1 (IN)
unnamed: D4.2 (A), J2.A4 (VBUS), J2.A9 (VBUS), J2.B4 (VBUS), J2.B9 (VBUS)
unnamed: D5.2 (A), R4.2
unnamed: F1.1, J1.2
unnamed: JP2.2 (C), U4.15 (A0)
unnamed: JP3.2 (C), U4.16 (A1)
unnamed: Q1.5 (I5), U4.5 (IO3)
unnamed: Q1.6 (I6), U4.4 (IO2)
unnamed: Q1.7 (I7), U4.3 (IO1)
unnamed: Q1.8 (I8), U4.2 (IO0)
unnamed: C2.1, R2.2, U2.3 (EN)
unnamed: C1.1, R1.2, SW1.2, U2.27 (IO0)
unnamed: U2.11 (IO18), U4.11 (~INT)
unnamed: R4.1, U2.33 (IO40)

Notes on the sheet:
Extension
LCD/BP

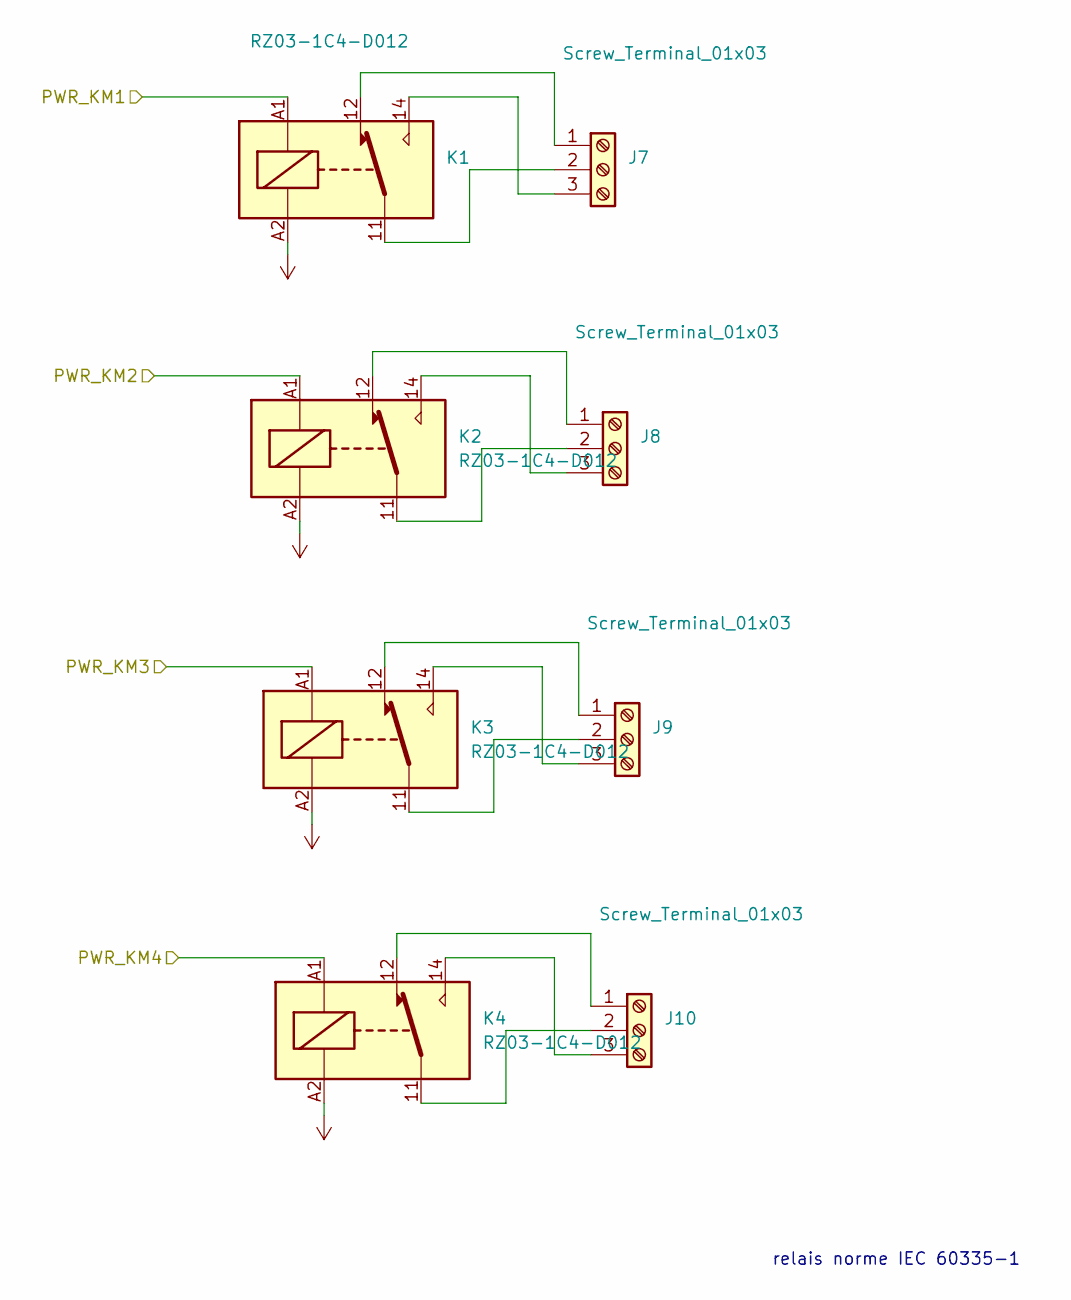
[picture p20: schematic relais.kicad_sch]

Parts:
J7, J8, J9, J10: Screw_Terminal_01x03; PhoenixContact_MCV_1,5_3-G-3.5_1x03_P3.50mm_Vertical
K1, K2, K3, K4: RZ03-1C4-D012; Relay_SPDT_Schrack-RT1-16A-FormC_RM5mm

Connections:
+12V: K1.A2, K2.A2, K3.A2, K4.A2; also elsewhere on the board
/relais/PWR_KM1: K1.A1; also elsewhere on the board
/relais/PWR_KM2: K2.A1; also elsewhere on the board
/relais/PWR_KM3: K3.A1; also elsewhere on the board
/relais/PWR_KM4: K4.A1; also elsewhere on the board
unnamed: J7.1, K1.12
unnamed: J7.2, K1.11
unnamed: J7.3, K1.14
unnamed: J8.1, K2.12
unnamed: J8.2, K2.11
unnamed: J8.3, K2.14
unnamed: J9.1, K3.12
unnamed: J9.2, K3.11
unnamed: J9.3, K3.14
unnamed: J10.1, K4.12
unnamed: J10.2, K4.11
unnamed: J10.3, K4.14

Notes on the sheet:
relais norme IEC 60335-1

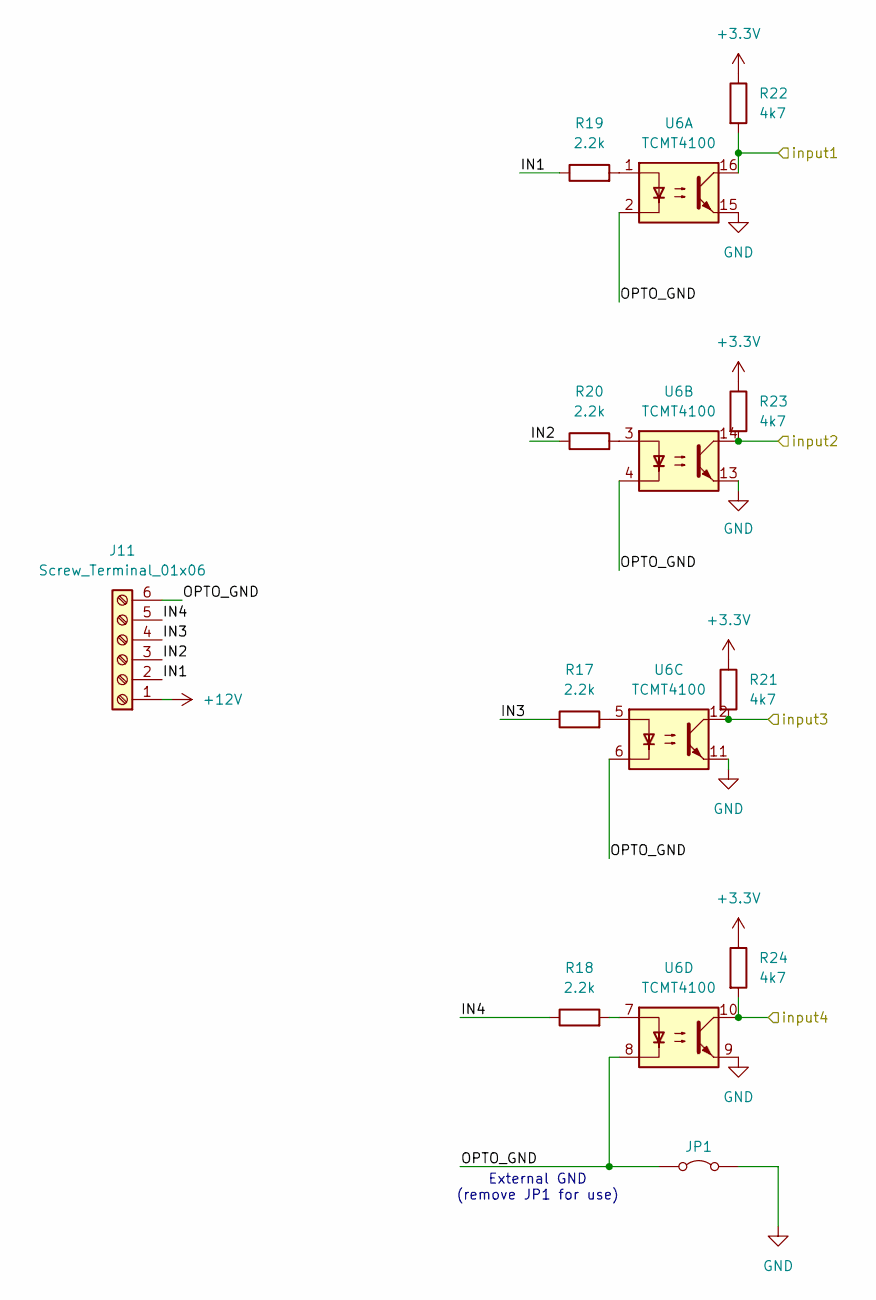
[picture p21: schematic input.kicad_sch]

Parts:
J11: Screw_Terminal_01x06; PhoenixContact_MCV_1,5_6-G-3.5_1x06_P3.50mm_Vertical
JP1: Jumper_2_Bridged; PinHeader_1x02_P2.54mm_Vertical
R17, R18, R19, R20: 2.2k; R_0805_2012Metric
R21, R22, R23, R24: 4k7; R_0402_1005Metric
U6: TCMT4100; SOP-16_4.4x10.4mm_P1.27mm

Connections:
+3.3V: R21.1, R22.1, R23.1, R24.1; also elsewhere on the board
+12V: J11.1; also elsewhere on the board
/input/IN1: J11.2, R19.1
/input/IN2: J11.3, R20.1
/input/IN3: J11.4, R17.1
/input/IN4: J11.5, R18.1
/input/OPTO_GND: J11.6, JP1.1 (A), U6.2, U6.4, U6.6, U6.8
/input/input1: R22.2, U6.16; also elsewhere on the board
/input/input2: R23.2, U6.14; also elsewhere on the board
/input/input3: R21.2, U6.12; also elsewhere on the board
/input/input4: R24.2, U6.10; also elsewhere on the board
GND: JP1.2 (B), U6.9, U6.11, U6.13, U6.15; also elsewhere on the board
unnamed: R17.2, U6.5
unnamed: R18.2, U6.7
unnamed: R19.2, U6.1
unnamed: R20.2, U6.3

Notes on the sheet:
External GND (remove JP1 for use)

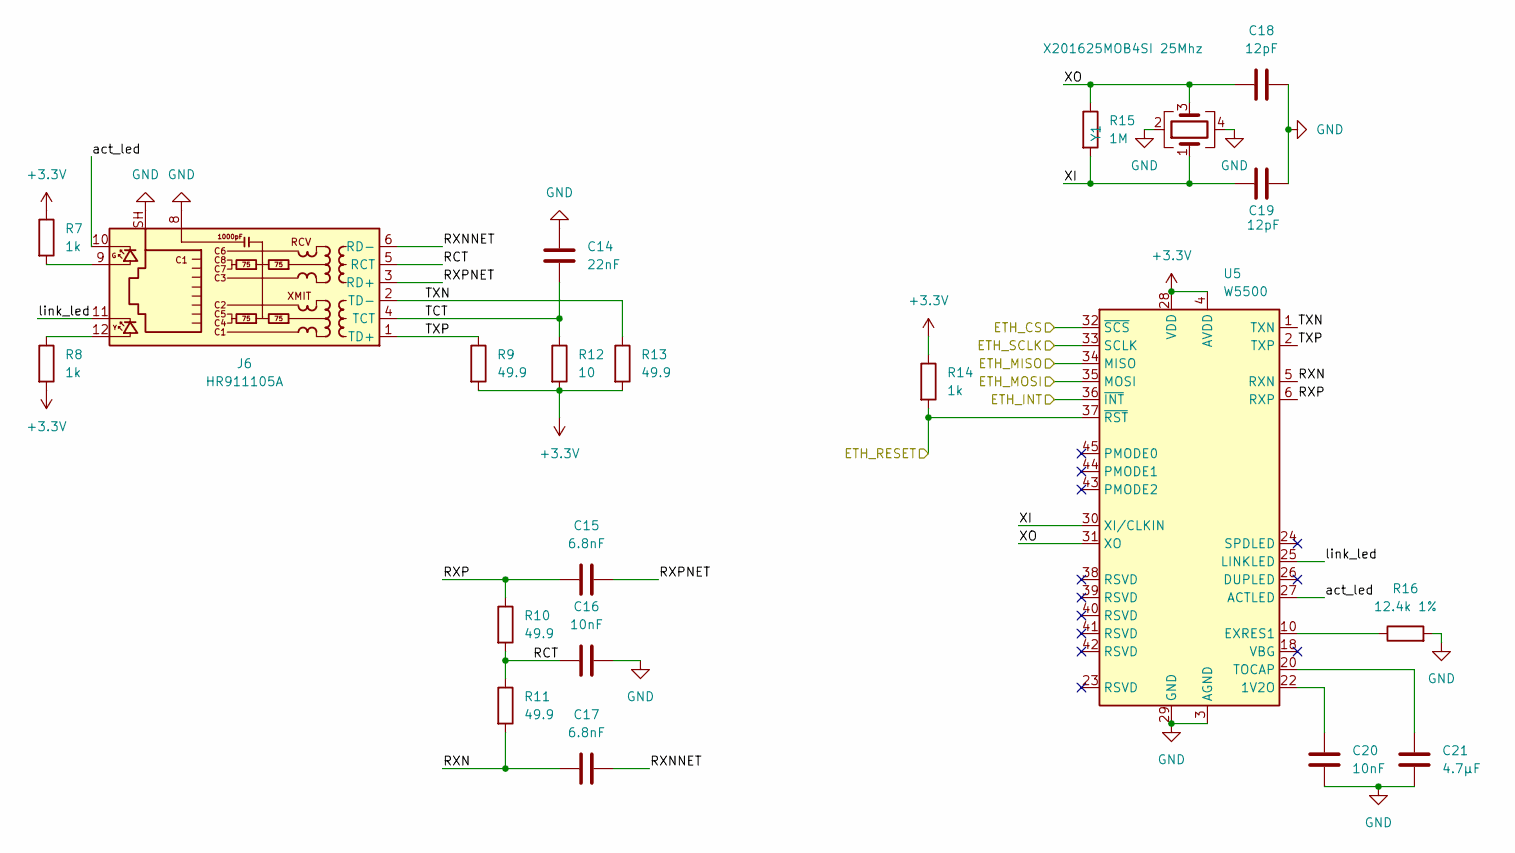
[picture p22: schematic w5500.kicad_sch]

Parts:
C14: 22nF; C_0402_1005Metric
C15, C17: 6.8nF; C_0402_1005Metric
C16, C20: 10nF; C_0402_1005Metric
C18, C19: 12pF; C_0402_1005Metric
C21: 4.7µF; C_0402_1005Metric
J6: HR911105A; RJ45_Hanrun_HR911105A_Horizontal
R7, R8, R14: 1k; R_0402_1005Metric
R9, R10, R11, R13: 49.9; R_0402_1005Metric
R12: 10; R_0402_1005Metric
R15: 1M; R_0402_1005Metric
R16: 12.4k 1%; R_0402_1005Metric
U5: W5500; LQFP-48_7x7mm_P0.5mm
Y1: X201625MOB4SI 25Mhz; Crystal_SMD_2016-4Pin_2.0x1.6mm

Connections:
+3.3V: R7.1, R8.2, R9.2, R12.2, R13.2, R14.1, U5.4 (AVDD), U5.8 (AVDD), U5.11 (AVDD), U5.15 (AVDD), U5.17 (AVDD), U5.21 (AVDD), U5.28 (VDD); also elsewhere on the board
/ETH_INT: U5.36 (~INT); also elsewhere on the board
/ETH_RESET: R14.2, U5.37 (~RST); also elsewhere on the board
/w5500/ETH_CS: U5.32 (~SCS); also elsewhere on the board
/w5500/ETH_MISO: U5.34 (MISO); also elsewhere on the board
/w5500/ETH_MOSI: U5.35 (MOSI); also elsewhere on the board
/w5500/ETH_SCLK: U5.33 (SCLK); also elsewhere on the board
/w5500/RCT: C16.2, J6.5 (RCT), R10.2, R11.1
/w5500/RXN: C17.1, R11.2, U5.5 (RXN)
/w5500/RXNNET: C17.2, J6.6 (RD-)
/w5500/RXP: C15.1, R10.1, U5.6 (RXP)
/w5500/RXPNET: C15.2, J6.3 (RD+)
/w5500/TCT: C14.2, J6.4 (TCT), R12.1
/w5500/TXN: J6.2 (TD-), R13.1, U5.1 (TXN)
/w5500/TXP: J6.1 (TD+), R9.1, U5.2 (TXP)
/w5500/XI: C19.2, R15.2, U5.30 (XI/CLKIN), Y1.1
/w5500/XO: C18.2, R15.1, U5.31 (XO), Y1.3
/w5500/act_led: J6.10, U5.27 (ACTLED)
/w5500/link_led: J6.11, U5.25 (LINKLED)
GND: C14.1, C16.1, C18.1, C19.1, C20.2, C21.2, J6.8, J6.SH, R16.2, U5.3 (AGND), U5.9 (AGND), U5.14 (AGND), U5.16 (AGND), U5.19 (AGND), U5.29 (GND), U5.48 (AGND), Y1.2, Y1.4; also elsewhere on the board
unnamed: J6.9, R7.2
unnamed: J6.12, R8.1
unnamed: C20.1, U5.22 (1V2O)
unnamed: R16.1, U5.10 (EXRES1)
unnamed: C21.1, U5.20 (TOCAP)

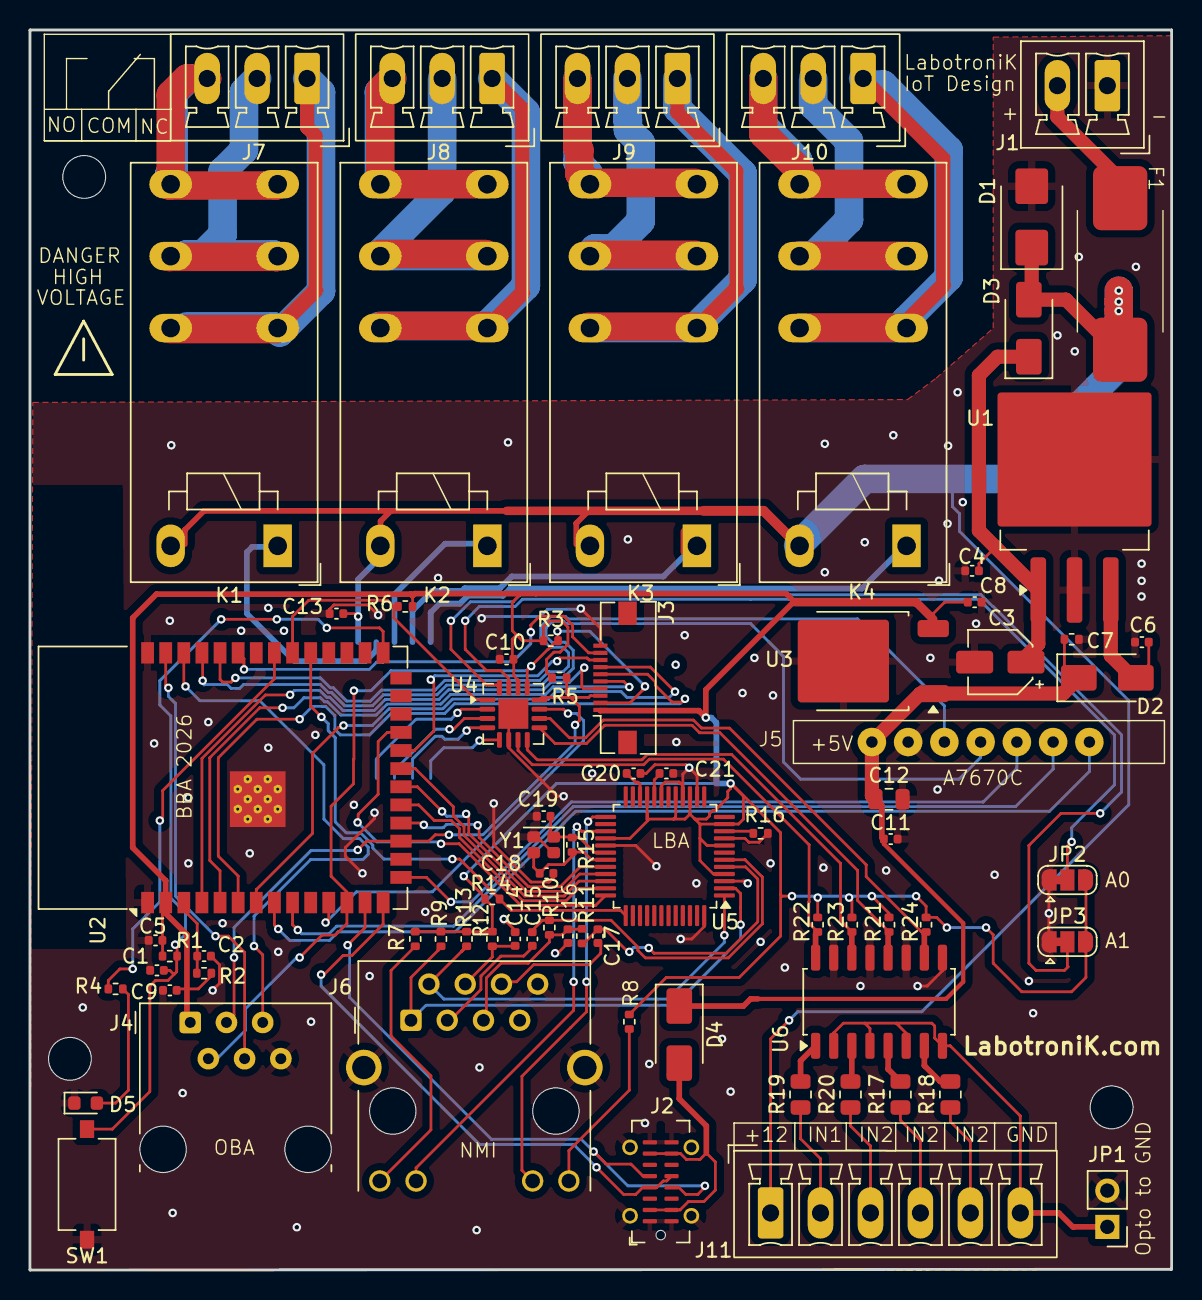
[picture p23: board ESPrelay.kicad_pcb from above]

Board: 2 copper layers, 80.0 x 86.9 mm, 78 parts (1 on the bottom side), 89 nets.

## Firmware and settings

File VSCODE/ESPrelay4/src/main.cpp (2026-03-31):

// main.cpp — ESP32-S3 + W5500 (Ethernet) + PCA9538 @0x70 + LittleFS
// + Règles simples (FOLLOW/AND/OR/XOR/TOGGLE_RISE/PULSE_RISE + delays)
// + Volet (shutter) sur 2 relais AU CHOIX, avec:
//   - réservation des relais (règles simples + override interdits sur ces relais)
//   - interlock UP/DOWN garanti
//   - dead-time entre inversions
//   - max_run_ms (sécurité)
//   - mode hold / toggle
//
// Endpoints:
//   GET  /                 -> index.html depuis LittleFS (streaming)
//   GET  /api/state        -> états inputs/relays/override + info eth + shutter
//   GET  /api/rules        -> JSON des règles (inclut shutters[])
//   GET  /api/net          -> config réseau (dhcp/static)
//   GET  /api/wifi         -> config/status WiFi (AP fallback)
//   PUT  /api/rules        -> remplace les règles (validation volet + conflits)
//   PUT  /api/net          -> applique + sauvegarde config réseau
//   PUT  /api/wifi         -> active/désactive le WiFi
//   POST /api/ota          -> update firmware (application/octet-stream)
//   POST /api/otafs        -> update LittleFS (application/octet-stream)
//   POST /api/override     -> override d'un relais (REFUSE si relais réservé volet)
//   POST /api/shutter      -> commande volet (UP/DOWN/STOP) (seul moyen "API" de bouger les relais volet)


#include <Arduino.h>
#include <Wire.h>
#include <SPI.h>
#include <Ethernet.h>
#include <WiFi.h>
#include <DNSServer.h>
#include <NimBLEDevice.h>
#include <Update.h>
#include <mbedtls/sha256.h>
#include <LittleFS.h>
#include <ArduinoJson.h>
#include <PubSubClient.h>
#include <cstring>
#include <OneWire.h>
#include <DallasTemperature.h>
#include <DHT.h>

#ifndef RXD0
#define RXD0 44
#endif
#ifndef TXD0
#define TXD0 43
#endif

#ifndef TINY_GSM_MODEM_SIM7600
#define TINY_GSM_MODEM_SIM7600
#endif
#ifndef TINY_GSM_RX_BUFFER
#define TINY_GSM_RX_BUFFER 1024
#endif
#include <TinyGsmClient.h>

static const uint8_t PIN_LED = 40;
static const uint8_t PIN_ONEWIRE = 1;  // DS18B20 (IO1)
static const uint8_t PIN_DHT = 2;      // DHT22 (IO2)
static const uint8_t PIN_FACTORY = 0;  // IO0 factory reset button (hold 10s at boot)
static const int PIN_MODEM_EN = 3;     // Modem power-enable (PEN)
static const int PIN_MODEM_RX = RXD0;  // ESP RXD0 <- A7670 TX
static const int PIN_MODEM_TX = TXD0;  // ESP TXD0 -> A7670 RX
static const uint32_t MODEM_UART_BAUD = 115200;
static const int MODEM_RX = PIN_MODEM_RX;
static const int MODEM_TX = PIN_MODEM_TX;
// Optional A7670 control pins (-1 = not connected on your PCB)
static const int PIN_MODEM_PWRKEY = 15;  // Active LOW pulse to power on/off
static const int PIN_MODEM_STATUS = -1;  // High when modem is on (if wired)
static const int PIN_MODEM_NET = 16;     // NETLIGHT output from modem
// A7670 HW design guide: PWRKEY low pulse >=50 ms, UART ready ~11.2 s
static const uint32_t MODEM_PWRKEY_ON_PULSE_MS = 80;
static const uint32_t MODEM_BOOT_WAIT_MS = 12000;

// GPRS credentials (used as defaults if MQTT GSM fields are empty)
static const char GPRS_DEFAULT_APN[] = "iot.1nce.net";
static const char GPRS_DEFAULT_USER[] = "";
static const char GPRS_DEFAULT_PASS[] = "";
// SIM card PIN (leave empty if not used)
static const char SIM_PIN[] = "";
// MQTT keepalive in seconds (default 30 min for low GSM traffic)
static const uint16_t MQTT_KEEPALIVE_SECONDS = 1800;
static const uint16_t MQTT_SOCKET_TIMEOUT_SECONDS = 1;
static const uint32_t MQTT_STARTUP_GRACE_MS = 15000;

// I2C (PCA9538)
static const int I2C_SDA = 8;     
static const int I2C_SCL = 9;     
static const uint8_t PCA_BASE_ADDR = 0x70;
static const uint8_t PCA_MAX_MODULES = 4;
static const uint8_t RELAYS_PER_MODULE = 4;
static const uint8_t INPUTS_PER_MODULE = 4;
static const uint8_t MAX_RELAYS = PCA_MAX_MODULES * RELAYS_PER_MODULE;
static const uint8_t MAX_INPUTS = PCA_MAX_MODULES * INPUTS_PER_MODULE;
static const uint8_t SHUTTER_MAX = MAX_RELAYS / 2;
static const uint8_t TEMP_MAX_SENSORS = 8;

// W5500 (SPI)
static const int PIN_W5500_CS = 10;
// ===============================================================

// relais actifs bas ? (si tes relais s'activent quand IO=0)
static const bool RELAY_ACTIVE_LOW = false;

// ===================== PCA9538 REGISTRES =======================
static const uint8_t REG_INPUT  = 0x00;
static const uint8_t REG_OUTPUT = 0x01;
static const uint8_t REG_POL    = 0x02;
static const uint8_t REG_CFG    = 0x03;

// ================== EthernetServer compat ESP32 =================
class EthernetServerCompat final : public EthernetServer {
public:
  explicit EthernetServerCompat(uint16_t port) : EthernetServer(port) {}
  void begin(uint16_t port = 0) override { (void)port; EthernetServer::begin(); }
};

EthernetServerCompat server(80);
static WiFiServer wifiServer(80);
static DNSServer wifiDns;

// BLE (read-only state JSON)
static NimBLEServer* bleServer = nullptr;
static NimBLECharacteristic* bleStateChar = nullptr;
static NimBLECharacteristic* bleStateReadChar = nullptr;
static bool bleClientConnected = false;
static uint32_t bleLastNotifyMs = 0;
static String bleServiceUuid;
static String bleStateCharUuid;
static String bleStateReadCharUuid;
static bool bleInitialized = false;
static bool bleEnabled = true;

static void buildStateJson(String &out);
static void buildStateJsonBle(String &out);
static bool saveBleCfg();
static bool loadBleCfg();
static bool clientWriteAll(Client& c, const uint8_t* data, size_t len, uint32_t timeoutMs = 1500);
static bool clientWriteString(Client& c, const String& s, uint32_t timeoutMs = 1500);
static String mqttDeviceId();
static String mqttBaseTopic();
static String mqttNodeId();

static String macHex12Upper(){
  uint64_t mac64 = ESP.getEfuseMac();
  uint8_t b[6];
  b[0] = (mac64 >> 40) & 0xFF;
  b[1] = (mac64 >> 32) & 0xFF;
  b[2] = (mac64 >> 24) & 0xFF;
  b[3] = (mac64 >> 16) & 0xFF;
  b[4] = (mac64 >> 8) & 0xFF;
  b[5] = (mac64 >> 0) & 0xFF;
  char buf[13];
  snprintf(buf, sizeof(buf), "%02X%02X%02X%02X%02X%02X", b[0], b[1], b[2], b[3], b[4], b[5]);
  return String(buf);
}

static String mqttDeviceId() {
  return macHex12Upper();
}

static void buildBleUuids(){
  String mac = macHex12Upper();
  bleServiceUuid = "6E400001-B5A3-F393-E0A9-" + mac;
  bleStateCharUuid = "6E400003-B5A3-F393-E0A9-" + mac;
  bleStateReadCharUuid = "6E400004-B5A3-F393-E0A9-" + mac;
}

// ===================== Réseau (à adapter) ======================
byte mac[6] = { 0,0,0,0,0,0 };

struct NetConfig {
  bool dhcp;
  IPAddress ip;
  IPAddress gw;
  IPAddress sn;
  IPAddress dns;
};

struct WifiConfig {
  bool enabled;   // autorise le WiFi AP fallback
  String ssid;
  String pass;
};

static NetConfig netCfg = {
  false,
  IPAddress(192,168,1,50),
  IPAddress(192,168,1,1),
  IPAddress(255,255,255,0),
  IPAddress(192,168,1,1)
};

static const IPAddress WIFI_AP_IP(192,168,4,1);
static const IPAddress WIFI_AP_GW(192,168,4,1);
static const IPAddress WIFI_AP_SN(255,255,255,0);
static const char* WIFI_DEFAULT_PASS = "esprelay4";

static WifiConfig wifiCfg = {
  true,
  String(""),
  String(WIFI_DEFAULT_PASS)
};

static bool wifiApOn = false;
static uint32_t wifiLastCheckMs = 0;

static void buildEthernetMac() {
  uint64_t mac64 = ESP.getEfuseMac();
  mac[0] = (mac64 >> 40) & 0xFF;
  mac[1] = (mac64 >> 32) & 0xFF;
  mac[2] = (mac64 >> 24) & 0xFF;
  mac[3] = (mac64 >> 16) & 0xFF;
  mac[4] = (mac64 >> 8) & 0xFF;
  mac[5] = 0xFE;
}

// ===================== MQTT ======================
struct MqttConfig {
  bool enabled;
  String transport;
  String host;
  uint16_t port;
  String user;
  String pass;
  String gsmMqttHost;
  uint16_t gsmMqttPort;
  String gsmMqttUser;
  String gsmMqttPass;
  String clientId;
  String base;
  String discoveryPrefix;
  bool retain;
  String apn;
  String gsmUser;
  String gsmPass;
};

static MqttConfig mqttCfg = {
  true,                    // enabled: active/desactive MQTT
  String("auto"),          // transport: ethernet | gsm | auto
  String("192.168.1.43"),  // host: broker MQTT principal (Ethernet/auto)
  1883,                    // port: port du broker principal
  String(""),              // user: identifiant MQTT principal
  String(""),              // pass: mot de passe MQTT principal
  String(""),              // gsmMqttHost: broker dedie GSM (optionnel)
  0,                       // gsmMqttPort: port broker dedie GSM
  String(""),              // gsmMqttUser: identifiant MQTT dedie GSM
  String(""),              // gsmMqttPass: mot de passe MQTT dedie GSM
  String(""),              // clientId: legacy UI field (runtime id = MAC12)
  String("espr4"),         // base: topic racine
  String("homeassistant"), // discoveryPrefix: prefix Home Assistant discovery
  true,                    // retain: publier les etats avec le flag retain
  String(GPRS_DEFAULT_APN),   // apn: APN data pour connexion GSM
  String(GPRS_DEFAULT_USER),  // gsmUser: user APN (GPRS)
  String(GPRS_DEFAULT_PASS)   // gsmPass: mot de passe APN (GPRS)
};

static EthernetClient mqttEth;
static HardwareSerial& SerialAT = Serial1;
static TinyGsm modem(SerialAT);
static TinyGsmClient mqttGsm(modem);
static PubSubClient mqttClientEth(mqttEth);
static PubSubClient mqttClientGsm(mqttGsm);
static uint32_t mqttLastConnectEthMs = 0;
static uint32_t mqttLastConnectGsmMs = 0;
static uint32_t mqttLastEthFailMs = 0;
static int mqttLastEthFailRc = 0;
static bool mqttEthAuthBlocked = false;
static bool mqttStartupGraceLogged = false;
static bool mqttAnnouncedEth = false;
static bool mqttAnnouncedGsm = false;
static bool mqttDisabledWarned = false;
static volatile bool mqttFastCommandPending = false;
static uint32_t mqttFastModeUntilMs = 0;
static bool modemSerialReady = false;
static bool modemReady = false;
static bool modemPowerKickDone = false;
static bool simPinChecked = false;
static bool gsmNetworkReady = false;
static bool gsmDataReady = false;
static uint32_t gsmLastTryMs = 0;
static uint32_t gsmLastDebugMs = 0;
static bool gsmLastNetConnected = false;
static bool gsmLastDataConnected = false;
static int gsmLastCsq = -1;
static int gsmLastDbm = 0;
static String gsmLastOperator = "";
static String gsmLastApn = "";
static String gsmLastIp = "";
static String gsmLastCcid = "";
static int gsmLastNetPin = -1;
static int gsmLastStatusPin = -1;
static uint32_t modemUartBaud = MODEM_UART_BAUD;
static int modemUartRxPin = MODEM_RX;
static int modemUartTxPin = MODEM_TX;
static String lastIpPubEth = "";
static String lastIpPubGsm = "";
static bool lastInputsPub[MAX_INPUTS] = {false};
static bool lastRelaysPub[MAX_RELAYS] = {false};
static int8_t lastRelayModePub[MAX_RELAYS] = {2};
static int lastShutterMove[SHUTTER_MAX] = {-1,-1};

// ===================== 1-Wire (DS18B20) ======================
static OneWire oneWire(PIN_ONEWIRE);
static DallasTemperature tempSensors(&oneWire);
static DeviceAddress tempAddr[TEMP_MAX_SENSORS];
static float tempC[TEMP_MAX_SENSORS];
static float lastTempPub[TEMP_MAX_SENSORS];
static uint8_t tempCount = 0;
static uint32_t lastTempReadMs = 0;

static uint8_t shuttersLimit();

static DHT dht(PIN_DHT, DHT22);
static bool dhtPresent = false;
static float dhtTempC = NAN;
static float lastDhtPub = NAN;
static float dhtHum = NAN;
static float lastDhtHumPub = NAN;
static bool dhtCheckDone = false;
static uint32_t dhtNextProbeMs = 0;


struct AuthConfig {
  String user;
  String pass;
};

static AuthConfig authCfg = {"admin", "admin"};

#ifndef FW_VERSION
#define FW_VERSION "dev"
#endif
#ifndef FW_TAG
#define FW_TAG ""
#endif


// ===================== Etat IO =====================
bool inputs[MAX_INPUTS] = {0};
bool prevInputs[MAX_INPUTS] = {0};
bool rawInputs[MAX_INPUTS] = {0};
uint32_t inputChangeMs[MAX_INPUTS] = {0};
static const uint32_t INPUT_DEBOUNCE_MS = 20;
bool virtualInputs[MAX_INPUTS] = {0};
bool lastVirtualPub[MAX_INPUTS] = {0};
bool combinedInputs[MAX_INPUTS] = {0};
bool prevCombinedInputs[MAX_INPUTS] = {0};

bool relays[MAX_RELAYS] = {0};
bool relayFromSimple[MAX_RELAYS] = {0};
bool relayFromShutter[MAX_RELAYS] = {0};

uint8_t pcaOutCache[PCA_MAX_MODULES] = {0};
bool pcaPresent[PCA_MAX_MODULES] = {false};
bool pcaAlive[PCA_MAX_MODULES] = {false};
uint8_t pcaFailCount[PCA_MAX_MODULES] = {0};
uint32_t pcaLastOkMs[PCA_MAX_MODULES] = {0};
uint8_t pcaCount = 0;
uint8_t totalRelays = 4;
uint8_t totalInputs = 4;

// Overrides : -1 auto, 0 force off, 1 force on (uniquement pour relais NON réservés)
int8_t overrideRelay[MAX_RELAYS];
String lastRulePub[MAX_RELAYS];
bool lastWifiPub = false;
bool lastBlePub = false;

// Mémoire toggle + pulse pour règles simples
bool toggleState[MAX_RELAYS] = {0};
uint32_t pulseUntilMs[MAX_RELAYS] = {0};

// Delay state pour règles simples
bool pendingTarget[MAX_RELAYS] = {0};
bool hasPending[MAX_RELAYS] = {0};
uint32_t pendingDeadlineMs[MAX_RELAYS] = {0};

// Réservation des relais par volet
bool reservedByShutter[MAX_RELAYS] = {false};

// ===================== Règles JSON en RAM ======================
JsonDocument rulesDoc;

// ===============================================================
// I2C helpers (STOP entre write et read => évite i2cWriteReadNonStop)
// ===============================================================
static bool i2cReadReg8(uint8_t addr, uint8_t reg, uint8_t &val) {
  for(int attempt=0; attempt<3; attempt++){
    Wire.beginTransmission(addr);
    Wire.write(reg);
    if (Wire.endTransmission(true) != 0) { delay(2); continue; } // STOP
    if (Wire.requestFrom((int)addr, 1) != 1) { delay(2); continue; }
    val = Wire.read();
    return true;
  }
  return false;
}

static bool i2cWriteReg8(uint8_t addr, uint8_t reg, uint8_t val) {
  for(int attempt=0; attempt<3; attempt++){
    Wire.beginTransmission(addr);
    Wire.write(reg);
    Wire.write(val);
    if (Wire.endTransmission(true) == 0) return true; // STOP
    delay(2);
  }
  return false;
}

// ===============================================================
// LittleFS helpers
// ===============================================================
static String readFile(const char* path) {
  if (!LittleFS.exists(path)) return "";
  File f = LittleFS.open(path, "r");
  if(!f) return "";
  String s = f.readString();
  f.close();
  return s;
}

static bool writeFile(const char* path, const String& data) {
  File f = LittleFS.open(path, "w");
  if(!f) return false;
  f.print(data);
  f.close();
  return true;
}

// ===============================================================
// WiFi AP helpers (fallback when Ethernet link OFF)
// ===============================================================
static String defaultWifiSsid() {
  uint64_t mac64 = ESP.getEfuseMac();
  uint8_t b2 = (mac64 >> 16) & 0xFF;
  uint8_t b1 = (mac64 >> 8) & 0xFF;
  uint8_t b0 = (mac64 >> 0) & 0xFF;
  char buf[32];
  snprintf(buf, sizeof(buf), "ESPRelay4-%02X%02X%02X", b2, b1, b0);
  return String(buf);
}

static void wifiCfgToJson(String &out) {
  static JsonDocument doc;
  doc.clear();
  doc["enabled"] = wifiCfg.enabled ? 1 : 0;
  doc["ssid"] = wifiCfg.ssid;
  doc["pass"] = wifiCfg.pass;
  doc["ap"] = wifiApOn ? 1 : 0;
  doc["ip"] = wifiApOn ? WiFi.softAPIP().toString() : "";
  doc["eth_link"] = (Ethernet.linkStatus()==LinkON) ? 1 : 0;
  serializeJsonPretty(doc, out);
}

static bool saveWifiCfg(){
  String out;
  wifiCfgToJson(out);
  return writeFile("/wifi.json", out);
}

static bool loadWifiCfg(){
  String s = readFile("/wifi.json");
  if(s.length() == 0){
    wifiCfg.enabled = true;
    wifiCfg.ssid = defaultWifiSsid();
    wifiCfg.pass = String(WIFI_DEFAULT_PASS);
    saveWifiCfg();
    Serial.println("[WIFI] created default /wifi.json");
    return true;
  }
  static JsonDocument doc;
  doc.clear();
  auto err = deserializeJson(doc, s);
  if(err){
    Serial.printf("[WIFI] JSON parse error -> keep default (%s)\n", err.c_str());
    wifiCfg.enabled = true;
    wifiCfg.ssid = defaultWifiSsid();
    wifiCfg.pass = String(WIFI_DEFAULT_PASS);
    return false;
  }
  String defSsid = defaultWifiSsid();
  wifiCfg.enabled = (doc["enabled"] | 1) ? true : false;
  wifiCfg.ssid = String((const char*)(doc["ssid"] | defSsid.c_str()));
  wifiCfg.pass = String((const char*)(doc["pass"] | WIFI_DEFAULT_PASS));
  if(wifiCfg.ssid.length() == 0){
    wifiCfg.ssid = defSsid;
  }
  if(wifiCfg.pass.length() < 8){
    wifiCfg.pass = String(WIFI_DEFAULT_PASS);
  }
  return true;
}

static void startWifiAp(){
  if(wifiApOn) return;
  WiFi.mode(WIFI_AP);
  WiFi.softAPConfig(WIFI_AP_IP, WIFI_AP_GW, WIFI_AP_SN);
  const bool ok = WiFi.softAP(wifiCfg.ssid.c_str(), wifiCfg.pass.c_str());
  if(ok){
    wifiServer.begin();
    wifiDns.start(53, "*", WiFi.softAPIP());
    wifiApOn = true;
    Serial.printf("[WIFI] AP ON SSID=%s PASS=%s IP=%s\n", wifiCfg.ssid.c_str(), wifiCfg.pass.c_str(), WiFi.softAPIP().toString().c_str());
  } else {
    wifiApOn = false;
    Serial.println("[WIFI] AP start FAILED");
  }
}

static void stopWifiAp(){
  if(!wifiApOn) return;
  wifiDns.stop();
  WiFi.softAPdisconnect(true);
  WiFi.mode(WIFI_OFF);
  wifiApOn = false;
  Serial.println("[WIFI] AP OFF");
}

static void updateWifiState(bool force=false){
  uint32_t now = millis();
  if(!force && (now - wifiLastCheckMs < 1000)) return;
  wifiLastCheckMs = now;
  // Keep AP available when enabled to guarantee local access even if LAN routing is broken.
  const bool shouldRun = wifiCfg.enabled;
  if(shouldRun && !wifiApOn) startWifiAp();
  else if(!shouldRun && wifiApOn) stopWifiAp();
}

static void applyWifiCfg(){
  updateWifiState(true);
}

// BLE config (LittleFS)
static void bleCfgToJson(String &out){
  static JsonDocument doc;
  doc.clear();
  doc["enabled"] = bleEnabled ? 1 : 0;
  serializeJsonPretty(doc, out);
}

static bool saveBleCfg(){
  String out;
  bleCfgToJson(out);
  return writeFile("/ble.json", out);
}

static bool loadBleCfg(){
  String s = readFile("/ble.json");
  if(s.length() == 0){
    bleEnabled = true;
    saveBleCfg();
    Serial.println("[BLE] created default /ble.json");
    return true;
  }
  static JsonDocument doc;
  doc.clear();
  auto err = deserializeJson(doc, s);
  if(err){
    Serial.printf("[BLE] JSON parse error -> keep default (%s)\n", err.c_str());
    bleEnabled = true;
    return false;
  }
  bleEnabled = (doc["enabled"] | 1) ? true : false;
  return true;
}

class BleServerCallbacks : public NimBLEServerCallbacks {
  void onConnect(NimBLEServer* s) override {
    bleClientConnected = true;
  }
  void onDisconnect(NimBLEServer* s) override {
    bleClientConnected = false;
    NimBLEDevice::startAdvertising();
  }
};
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
void loop() {
  // Serve HTTP first to keep UI/API responsive even if other tasks slow down.
  handleHttp();

  // Process MQTT early so incoming commands are applied in the same loop cycle.
  mqttLoop();
  if (mqttFastCommandPending) {
    // Fast path: apply command immediately, then continue normal cycle.
    shutterTick();
    evalSimpleRules();
    buildFinalRelays();
    pcaApplyRelays();
    mqttFastCommandPending = false;
  }

  // read inputs early to update module status before serving HTTP
  pcaReadInputs();
  debounceInputs();

  // combine physical + virtual inputs for rules/edges
  for(int i=0;i<totalInputs;i++){
    combinedInputs[i] = inputs[i] || virtualInputs[i];
  }

  updateWifiState();
  heartbeatTick();
  bleTick();

  // tick shutter BEFORE computing simple rules, so it can use prevInputs if needed
  shutterTick();

  // compute simple rules (for all relays)
  evalSimpleRules();

  // build final outputs with ownership rules:
  // simple -> shutter overwrites reserved -> overrides (non-reserved only) -> final safety
  buildFinalRelays();

  // apply outputs
  pcaApplyRelays();

  // Temperature polling
  if(millis() - lastTempReadMs > 5000){
    lastTempReadMs = millis();
    if(tempCount > 0){
      tempSensors.requestTemperatures();
      for(uint8_t i=0;i<tempCount;i++){
        float c = tempSensors.getTempC(tempAddr[i]);
        tempC[i] = c;
      }
    }
    // DHT reads can block when sensor is absent; once not detected, probe only occasionally.
    const uint32_t nowMs = millis();
    const bool shouldProbeDht = dhtPresent || !dhtCheckDone || nowMs >= dhtNextProbeMs;
    if (shouldProbeDht) {
      float dhtC = dht.readTemperature();
      float dhtH = dht.readHumidity();
      if(!isnan(dhtC) || !isnan(dhtH)){
        if(!dhtPresent) mqttAnnouncedEth = false;
        if(!dhtPresent) Serial.println("[DHT] detected");
        dhtPresent = true;
        if(!isnan(dhtC)) dhtTempC = dhtC;
        if(!isnan(dhtH)) dhtHum = dhtH;
        dhtCheckDone = true;
        dhtNextProbeMs = nowMs + 5000;
      } else {
        if(!dhtCheckDone) {
          Serial.println("[DHT] not detected");
          dhtCheckDone = true;
        }
        if (!dhtPresent) {
          dhtNextProbeMs = nowMs + 60000;
        }
      }
    }
  }

  // update prev inputs for edge-based rules/toggle/pulse
  for(int k=0;k<totalInputs;k++){
    prevInputs[k] = inputs[k];
    prevCombinedInputs[k] = combinedInputs[k];
  }

  // 1Hz log
  /*
  static uint32_t t0 = 0;
  if(millis() - t0 > 1000){
    t0 = millis();
    logConnectivityTransitions();
    String e, r, res;
    for(int i=0;i<totalInputs;i++) e += String(inputs[i] ? 1 : 0);
    for(int i=0;i<totalRelays;i++) r += String(relays[i] ? 1 : 0);
    for(int i=0;i<totalRelays;i++) res += String(reservedByShutter[i] ? 1 : 0);
    Serial.printf("[STATE] E=%s  R=%s  RES=%s\n",
      e.c_str(), r.c_str(), res.c_str()
    );
  }
  */

  delay(2);
}

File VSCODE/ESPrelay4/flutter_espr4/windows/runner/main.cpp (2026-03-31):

#include <flutter/dart_project.h>
#include <flutter/flutter_view_controller.h>
#include <windows.h>

#include "flutter_window.h"
#include "utils.h"

int APIENTRY wWinMain(_In_ HINSTANCE instance, _In_opt_ HINSTANCE prev,
                      _In_ wchar_t *command_line, _In_ int show_command) {
  // Attach to console when present (e.g., 'flutter run') or create a
  // new console when running with a debugger.
  if (!::AttachConsole(ATTACH_PARENT_PROCESS) && ::IsDebuggerPresent()) {
    CreateAndAttachConsole();
  }

  // Initialize COM, so that it is available for use in the library and/or
  // plugins.
  ::CoInitializeEx(nullptr, COINIT_APARTMENTTHREADED);

  flutter::DartProject project(L"data");

  std::vector<std::string> command_line_arguments =
      GetCommandLineArguments();

  project.set_dart_entrypoint_arguments(std::move(command_line_arguments));

  FlutterWindow window(project);
  Win32Window::Point origin(10, 10);
  Win32Window::Size size(1280, 720);
  if (!window.Create(L"flutter_espr4", origin, size)) {
    return EXIT_FAILURE;
  }
  window.SetQuitOnClose(true);

  ::MSG msg;
  while (::GetMessage(&msg, nullptr, 0, 0)) {
    ::TranslateMessage(&msg);
    ::DispatchMessage(&msg);
  }

  ::CoUninitialize();
  return EXIT_SUCCESS;
}

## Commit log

2026-01-07 avancement carte 4 relays
    [D5MG-BASE.SLDPRT, D5MG-BODY.SLDPRT, D5MG-COVER.SLDPRT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]
2026-01-16 production 1
    [bom.csv, designators.csv, positions.csv]
2026-01-30 Réorganisation : tous les fichiers déplacés dans kicad/
    [D5MG-BASE.SLDPRT, D5MG-BODY.SLDPRT, D5MG-COVER.SLDPRT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]
2026-01-30 Ajout de .gitignore pour KiCad
2026-01-30 Réorganisation : tous les fichiers dans kicad/
    [D5MG-BASE.SLDPRT, D5MG-BODY.SLDPRT, D5MG-COVER.SLDPRT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]
2026-01-30 Ajout du fichier .gitignore pour KiCad
2026-02-01 page de log pour modif des setup OK. ajout bouton de reset et les status pour reset firmware. a tester
    [main.cpp]
2026-02-03 affichage erreur comm I2C module, UI: affichage fw git
2026-02-04 minor bug update. add daughter pcb initial commit
    [ESPrelay.kicad_sch, daughter_4relays.kicad_pcb, daughter_4relays.kicad_sch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]
2026-02-10 add virtual input for HA. add button for BLE/wifi
2026-02-20 feat: add GSM MQTT mode telemetry, optimize Flutter MQTT dashboard stability, and refresh app brandin
    [main.cpp]
2026-03-27 feat: stabilise MQTT auto ETH+GSM et fiabilise l'UI web
    Changements majeurs:
    - MQTT: mode transport par défaut aligné sur auto (fallback parsing + UI), avec statut UI recalculé proprement en mode auto.
    - MQTT GSM: connexion GSM considérée active uniquement si modem + data réellement UP, évite les faux états "Connected (GSM)".
    - HTTP/UI: retours d'action locaux ajoutés sur les boutons critiques (save/auth/net/rules/apply), réduction des blocages perçus côté webapp.
    - Sécurité: suppression de wifi.pass dans /api/state (endpoint non authentifié).
    - Backup restore: validation sans effets de bord + logique de rollback pour éviter les applications partielles en cas d'échec d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
    [main.cpp]
2026-03-30 feat: add input naming/VIN control and improve 1-Wire sensor scan
2026-03-30 MQTT: device-id MAC, base espr4, fallback GSM guardrails, and UI updates
    Firmware (ESPRelay4):\n- Use MAC12 as MQTT device ID (no ER4- prefix)\n- Default/normalized base topic set to espr4 (with legacy esprelay4 migration)\n- Fix transport normalization to keep ethernet mode\n- Improve GSM fallback behavior in auto/gsm modes to avoid private-host reconnect loops\n- Expose device_id/base_effective in MQTT/state payloads\n\nWeb UI:\n- Move Retain under Enable MQTT\n- Remove Base topic field and force base=espr4 in UI payload\n- GSM broker label/default updates (no optional text, empty broker, port 1883)\n- Rework MQTT status pills under Transport (MQTT HA + MQTT GSM)\n\nFlutter app:\n- Connect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
    [main.cpp]
2026-10-11 feat: mise à jour majeure du firmware ESPRelay4 et applications
    Firmware ESP32-S3:
    - Support MQTT étendu avec transport Ethernet/GSM/auto
    - Améliorations BLE (protocole de commandes, notifications)
    - Corrections critiques sur les volets (dead-time, max_run_ms, sécurité)
    - Support multi-modules PCA9538 (jusqu'à 4 modules = 16 E/S)
    - Capteurs DS18B20 et DHT22 intégrés
    - OTA par Ethernet avec sauvegarde automatique des configurations
    Interface Web (LittleFS):
    - Traductions complètes EN/FR
    - Refonte du dashboard et des onglets de configuration
    - Support JSON pour backup/restore complet
    Applications Flutter:
    - flutter_espr4: refactoring complet, gestion multi-cartes, scan BLE/QR
    - flut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
